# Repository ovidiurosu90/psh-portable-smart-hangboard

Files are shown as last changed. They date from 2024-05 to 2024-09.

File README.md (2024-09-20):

# [PSH Portable Smart Hangboard](https://github.com/ovidiurosu90/psh-portable-smart-hangboard)

## Abstract
### Problem
Help people get better at climbing by improving their finger strength

### Solution
Provide a portable smart hangboard to use for finger strength training

### How
- the whole project is open-source, and can be replicated by interested parties (note it requires a variety of skills like setting up a web server, 3d printing, soldering & crimping)
- the hangboard measures the pressure applied to the hanghold by using a couple of load cells
- the training plans are set in Google Sheets

## Important Links

| Name | README |
| --- | --- |
| BOM Bill Of Materials | [BOM.md](BOM.md) |
| How To Build | [HOWTOBUILD.md](HOWTOBUILD.md) |

## Images

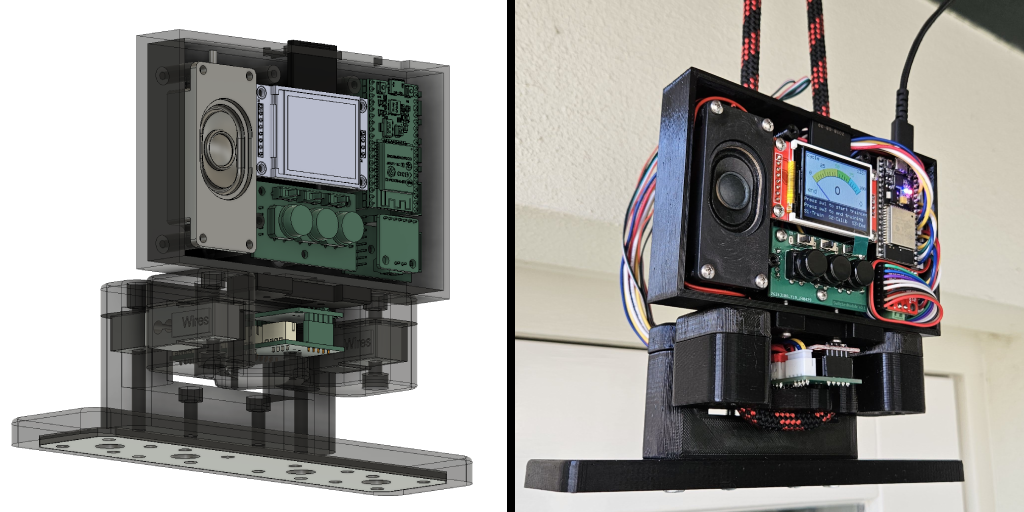
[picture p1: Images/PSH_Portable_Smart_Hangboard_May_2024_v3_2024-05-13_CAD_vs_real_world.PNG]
CAD vs Real World


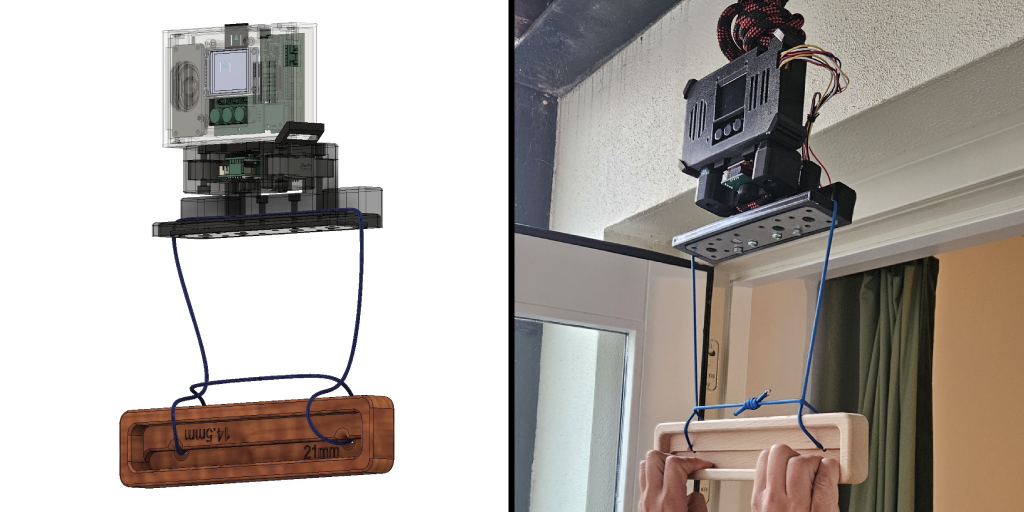
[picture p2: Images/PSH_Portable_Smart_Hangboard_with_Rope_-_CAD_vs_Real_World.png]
Wood non-slippery holds - CAD vs Real World


## Functionality of switches
- There are 3 big black momentary switches (labeled SW1, SW2 and SW3)
- There are 3 small toggle switches (labeled SW4, SW5 and SW6)
- The functionality of the switches is described below

### SW1
If SW4 is toggled ON: start training

Else: decrease volume

### SW2
If SW4 is toggled ON: start calibrating

Else: store volume into NVS (only if SW5 is toggled ON)

### SW3
If SW4 is toggled ON: end training

Else: increase volume

### SW4
If toggled ON: show train menu

Else: show volume menu

### SW5
If toggled ON: allow NVS to be updated (for calibration and for volume)

Else: don't allow NVS to be updated

### SW6
Not used at the moment

## Usage
- Power the microcontroller via its micro-USB port (+5V)
- Wait for the microcontroller to finish setting things up (it's ready when it says 'idle' on the lower left side of analog meter)
- Configure the training parameters in the spreadsheet via Goole Sheets
- The training program starts with a rest cycle, followed by an activity cycle, then repeat
- Example

| totalCycles | activityTotalSeconds | restTotalSeconds | scaleLowerLimitGrams | scaleUpperLimitGrams |
| --- | --- | --- | --- | --- |
| 6 | 10 | 20 | 55000 | 90000 |

- For the example above, we'll have 6 cycles as follows:
    - cycle 1: rest for 20 seconds
    - cycle 2: activity for 10 seconds
    - cycle 3: rest for 20 seconds
    - cycle 4: activity for 10 seconds
    - cycle 5: rest for 20 seconds
    - cycle 6: activity for 10 seconds

- Start the training by pressing SW1 (note SW4 should be toggled ON)
- The score is updated only in the activity cycles (cycle 2, 4 and 6 in the example above)
- The score is calculated as follows:
    - each second there are 2 scale measurements
    - let's say we have 3 activity cycles of 10 seconds
    - which means 3x 10x 2 measurements
    - we just sum up the 60 measurements (in kg)
- For the exapmle above, the score can be the following:
    - score: 2017 (which is a sum of all the scale measurements)
    - history: 73,70,70,68,71,70,70,70,69,70,62,65,67,68,66,66,66,67,64,64,68,66,67,67,67,65,66,67,65,63
- In the future, the scoring method may be different, as at the moment, we don't penalize out-of-bounds measurements, and we don't reward in-bounds measurements

## Wiring

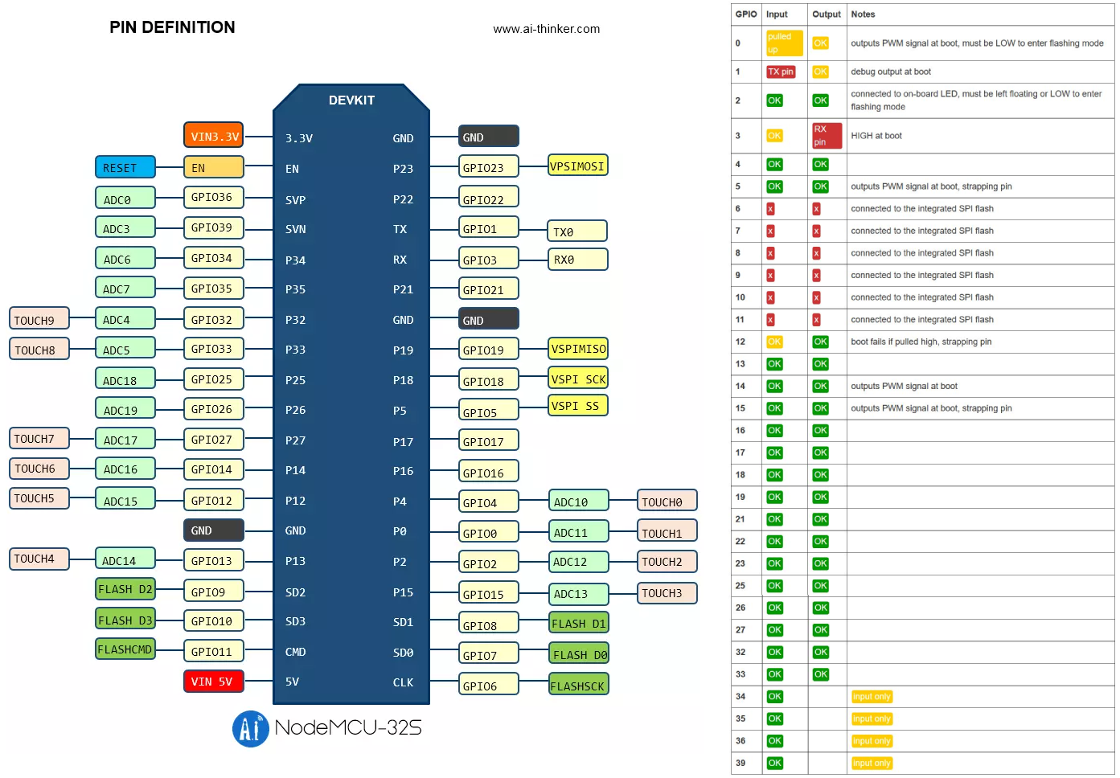
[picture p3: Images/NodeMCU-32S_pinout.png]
NodeMCU 32S Pinout


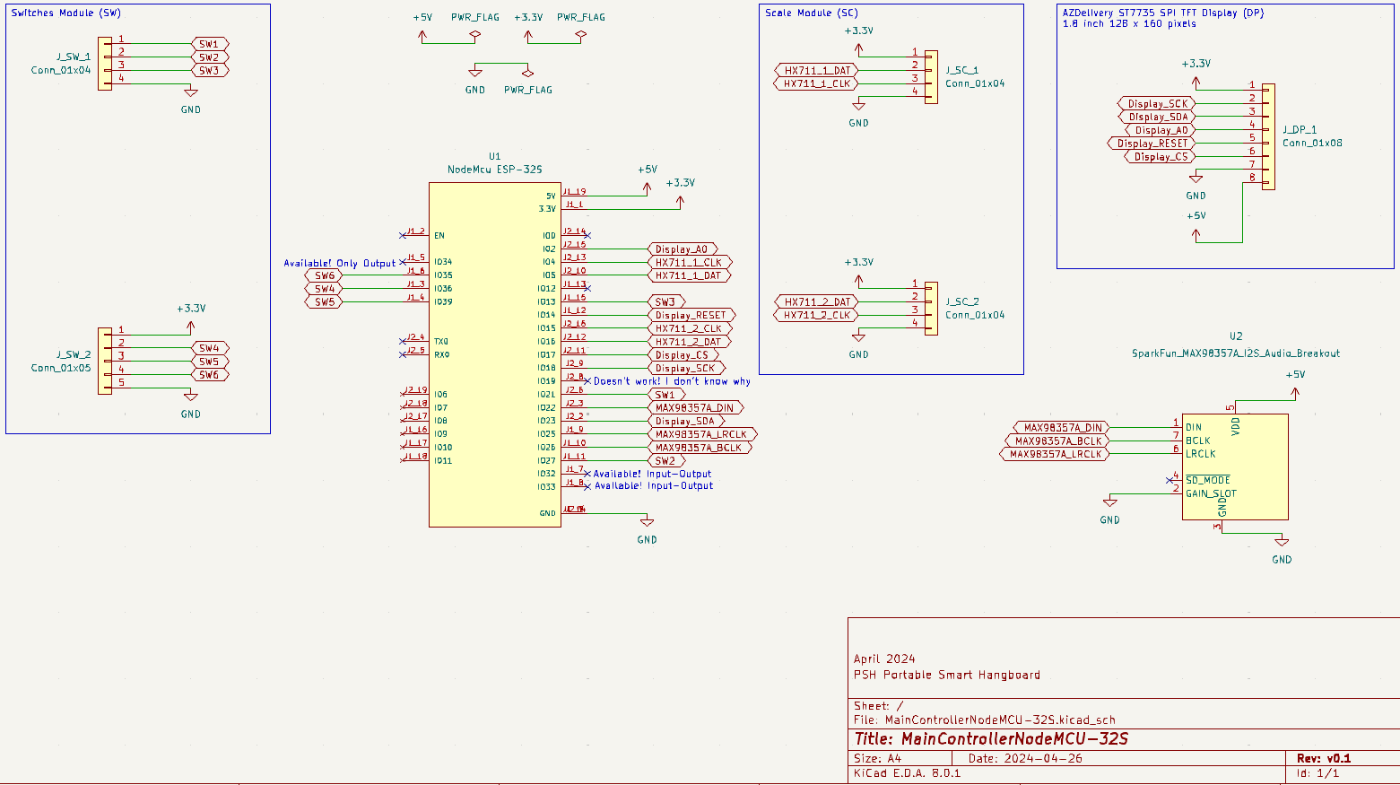
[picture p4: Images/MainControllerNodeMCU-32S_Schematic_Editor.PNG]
MainControllerNodeMCU-32S Schematic Editor


| [NodeMcu ESP-32S Lua ESP-WROOM-32](https://opencircuit.shop/product/nodemcu-esp-32s-lua-esp-wroom-32-wifi) | [SparkFun HX711 Load Cell Amplifier](https://eu.robotshop.com/products/hx711-load-cell-amplifier?variant=42600661942440) => NOTE we need to solder male pins |
| --- | --- |
| 5, 4 | DAT1, CLK1 |
| 16, 15 | DAT2, CLK2 |
| +3.3V | VDD, VCC |
| GND | GND |

| [NodeMcu ESP-32S Lua ESP-WROOM-32](https://opencircuit.shop/product/nodemcu-esp-32s-lua-esp-wroom-32-wifi) | [AZDelivery ST7735 SPI TFT Display 1.8 inch 128 x 160 pixels](https://www.amazon.nl/dp/B078J5TS2G/ref=pe_28126711_487805961_TE_item?th=1) =>  [guide](https://www.az-delivery.de/en/blogs/azdelivery-blog-fur-arduino-und-raspberry-pi/1-8-toll-tft-am-esp-32-dev-kit-c-betreiben) |
| --- | --- |
| +5V | VCC |
| GND | GND |
| G17 | CS |
| G14 | Reset / RST |
| G2 | A0 / DC |
| G23 | Sda / MOSI |
| G18 | Sck / SCLK |
| 3.3V | LED |

| [NodeMcu ESP-32S Lua ESP-WROOM-32](https://opencircuit.shop/product/nodemcu-esp-32s-lua-esp-wroom-32-wifi) | [AZDelivery ST7735 SPI TFT Display 1.8 inch 128 x 160 pixels](https://www.amazon.nl/dp/B078J5TS2G/ref=pe_28126711_487805961_TE_item?th=1) => [guide](https://randomnerdtutorials.com/guide-to-1-8-tft-display-with-arduino/) |
| --- | --- |
| G33 | CS |
| G23 | MOSI (shared with display) |
| G19 | MISO |
| G18 | SCK / SCLK (shared with display |

NOTE At the moment the custom PCB for the MainControllerNodeMCU-32S module needs a small improvement. Currently it’s missing a 4-pin connection for interfacing with the SD card on the TFT display. You can either modify the project and add the connector on the PCB (before placing the order), or make the 4 connections manually (solder the 4 wires directly on the PCB, picture found below). Follow the issue on GitHub for updates: [\[PCB\] Update Custom PCB for MainControllerNodeMCU-32S #8](https://github.com/ovidiurosu90/psh-portable-smart-hangboard/issues/8).

| [NodeMcu ESP-32S Lua ESP-WROOM-32](https://opencircuit.shop/product/nodemcu-esp-32s-lua-esp-wroom-32-wifi) | [SparkFun MAX98357A I2S Audio Breakout](https://opencircuit.shop/product/sparkfun-i2s-audio-breakout-max98357a) => [guide](https://learn.sparkfun.com/tutorials/i2s-audio-breakout-hookup-guide/all) |
| --- | --- |
| +5V (if we use +3.3V the volume fluctuates) | VDD |
| GND | GND |
| \- | SD |
| GND | GAIN (+12dB, without this it will be +9dB) |
| G22 | DIN / DOUT |
| G26 | BCLK |
| G25 | LRCLK |

| [NodeMcu ESP-32S Lua ESP-WROOM-32](https://opencircuit.shop/product/nodemcu-esp-32s-lua-esp-wroom-32-wifi) | SwitchesModule (my custom PCB) |
| --- | --- |
| G21 | SW1 |
| G27 | SW2 |
| G13 | SW3 |
| GND | GND |
| +3.3V | ~ pull-up resistors |
| G36 | SW4 with 10k resistor to +3.3V |
| G39 | SW5 with 10k resistor to +3.3V |
| G35 | SW6 with 10k resistor to +3.3V |
| GND | GND |

| [NodeMcu ESP-32S Lua ESP-WROOM-32](https://opencircuit.shop/product/nodemcu-esp-32s-lua-esp-wroom-32-wifi) | ? |
| --- | --- |
| G32 (input-output pin) | Available |
| G34 (only output pin) | Available |

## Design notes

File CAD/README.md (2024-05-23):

# CAD
I am using Autodesk Fusion 360 as the main CAD software.
In this folder you can find the .f3z file, which contains all the .f3d Fusion 360 3D design files. I chose to upload the f3z file instead of a bundle of STEP files as it holds the complete design and it's way easier to update.

NOTE Install Autodesk Fusion 360, then import everything by following the steps:

1. create a new project by clicking ‘New Project’ in the left toolbar
1. open the new project by double clicking its name
1. upload the .f3d archive from GitHub ([CAD](CAD)) by clicking ‘Upload’ in the left toolbar
1. wait a few minutes, this is uploading multiple designs to your Fusion 360 project
1. open the main assembly (PSH Portable Smart Hangboard May 2024) by double clicking its name. It should look something like this

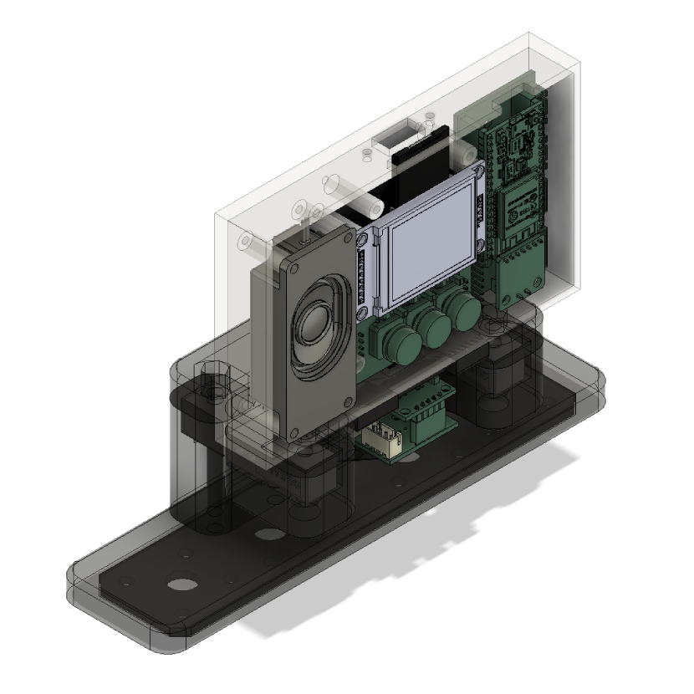
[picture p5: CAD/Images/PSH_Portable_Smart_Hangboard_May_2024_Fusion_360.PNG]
PSH Portable Smart Hangboard May 2024 in Fusion 360


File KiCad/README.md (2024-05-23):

# KiCad
I am using KiCad 8.0 as the main electronics design software. The project at the moment has 3 custom PCBs that were designed with this tool.
You have to send the gerber files to a PCB manufacturer, then solder the connectors / components before assembling.

## Images

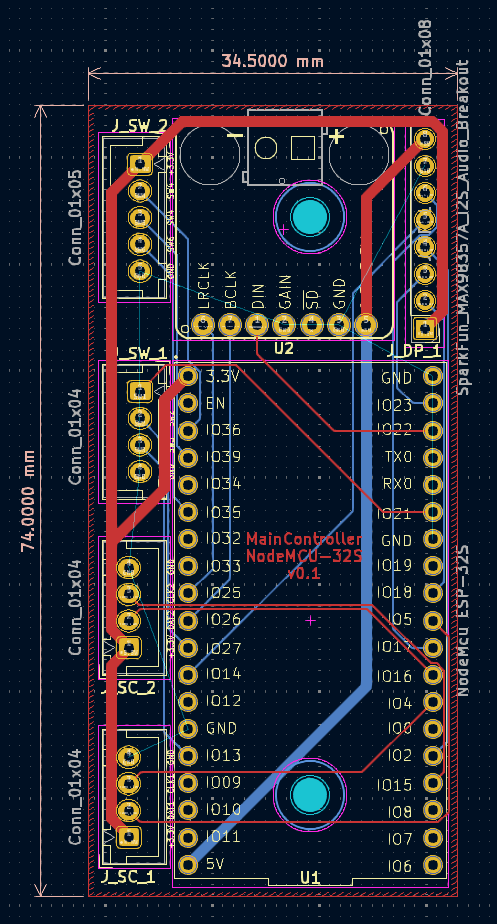
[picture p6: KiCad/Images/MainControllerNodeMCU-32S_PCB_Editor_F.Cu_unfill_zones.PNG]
MainControllerNodeMCU-32S PCB Editor F.Cu unfill zones


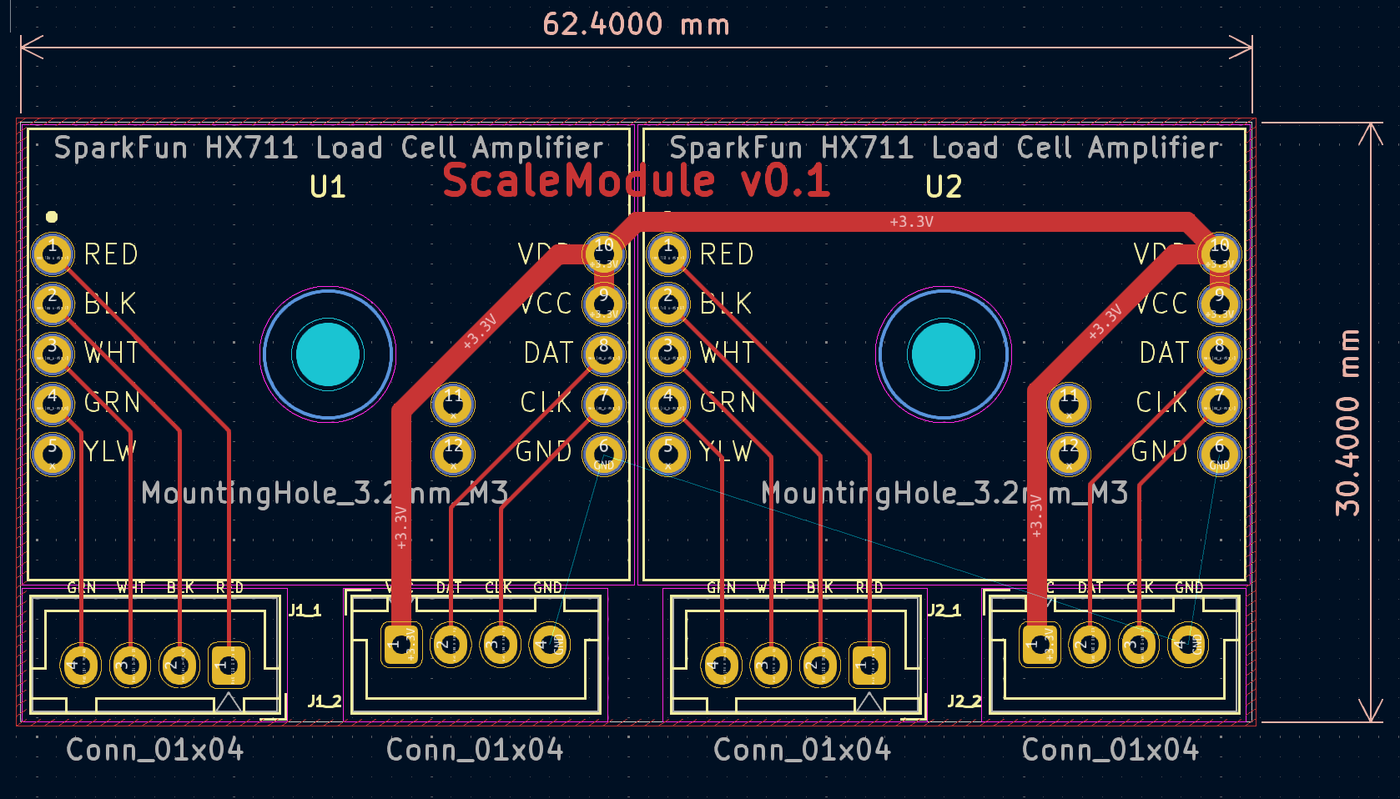
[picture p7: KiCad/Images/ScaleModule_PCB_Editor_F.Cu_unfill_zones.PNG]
ScaleModule PCB Editor F.Cu unfill zones


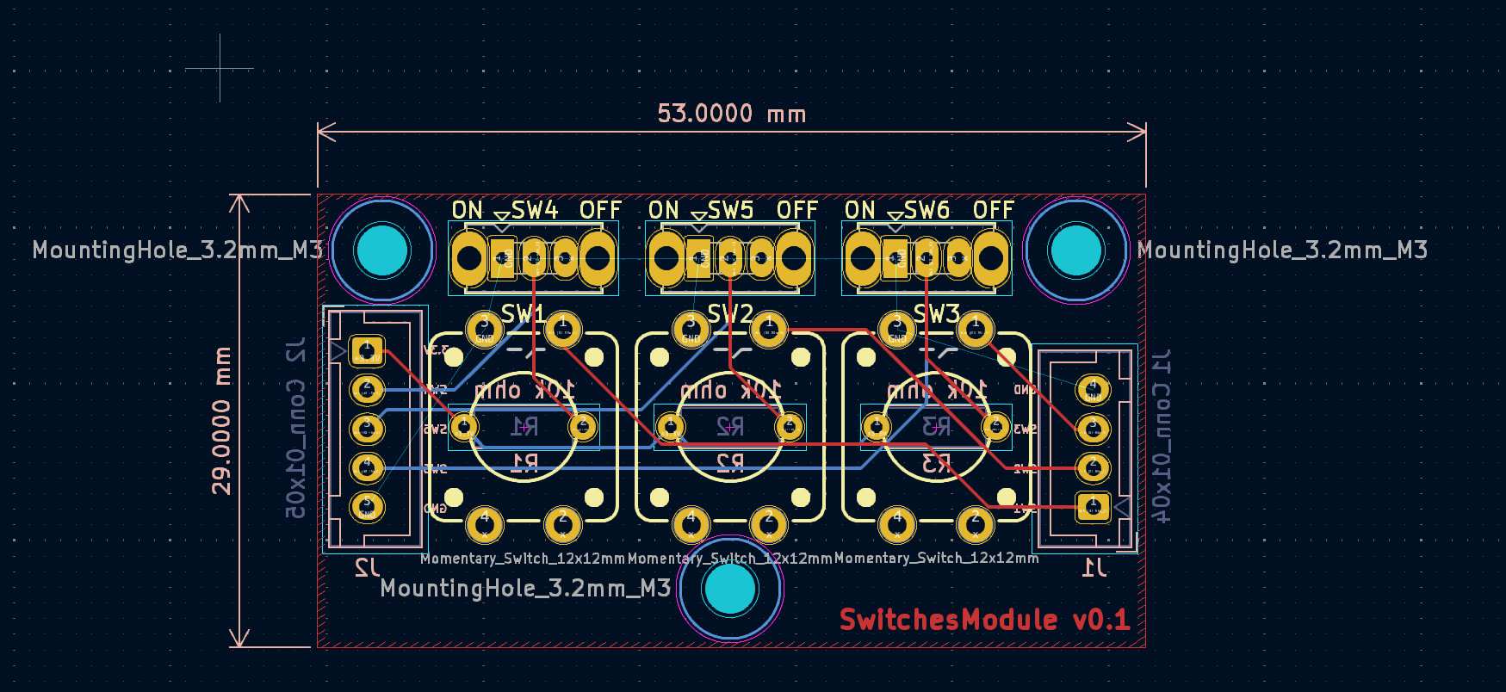
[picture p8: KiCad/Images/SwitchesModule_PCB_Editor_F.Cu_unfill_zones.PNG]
SwitchesModule PCB Editor F.Cu unfill zones


## Configuration
### PCB Layers
- F.Cu => tracks & maybe name + version
- B.Cu => tracks & maybe name + version
- F.Adhesive => vias + pads
- B.Adhesive => vias + pads
- F.Paste => vias + pads
- B.Paste => vias + pads
- F.Silkscreen => labels front
- B.Silkscreen => labels back + pcb dimensions (NOTE in 3D Viewer, you have to make visible Off-board Silkscreen)
- F.Mask => pads
- B.Mask => pads
- User.Comments => mounting holes exterior
- Edge.Cuts => pcb edges
- F.Courtyard => edges components on the pcb front
- B.Courtyard => edges components on the pcb back
- F.Fab => references footprints front
- B.Fab => references footprints back

### Design Rules -> Constraints
- Minimum track width 0.2 mm
- Minimum via diameter => 0.7 mm
- Minimum through hole => 0.4 mm
- Hole to hole clearance => 0.25mm
- Minimum uVia diameter => 0.7 mm
- Minimum uVia hole => 0.4mm
- Minimum text height => 0.5mm

### Design Rules -> Net Classes
- Default
    - Clearance 0.2 mm
    - Track Width 0.2 mm
    - Via Size 0.6 mm
    - Via Hole 0.3 mm
    - uVia Size 0.3 mm
    - uVia Hole 0.1 mm
    - DP Width 0.2
    - DP Gap 0.25 mm
- Custom
    - Clearance 0.3 mm
    - Track Width 0.3 mm
    - Via Size 0.8 mm
    - Via Hole 0.4 mm
    - uVia Size 0.6 mm
    - uVia Hole 0.2 mm
    - DP Width 0.2
    - DP Gap 0.25 mm
- Power
    - Clearance 0.8 mm
    - Track Width 0.8 mm
    - Via Size 1.2 mm
    - Via Hole 0.6 mm
    - uVia Size 0.6 mm
    - uVia Hole 0.2 mm
    - DP Width 0.2
    - DP Gap 0.25 mm

### Design Rules -> Pre-defined Sizes
- Tracks 1 mm width
- Vias 1.2 mm diameter, 1 mm hole
*Tracks: 1 mm for power, netclass width for everything else*

## Validation
A. Schematic Editor
1. Annotate Schematic => make screenshots
2. Electrical Rules Checker
3. Assign Footprints => make screenshots

B. PCB Editor
0. File -> Board Setup -> Import Settings from Another Board...
1. Check F.Cu with unfill zones => make screenshots
2. Check B.Cu with unfill zones => make screenshots
3. Check F.Cu with fill zones => make screenshots
4. Check B.Cu with fill zones => make screenshots
5. Check 3D Viewer front (toggle Through-hole Models on & off) => make screenshots
6. Check 3D Viewer back (toggle Through-hole Models on & off) => make screenshots

7. Check the connections
8. Check order & orientation of the pins for the connectors (e.g. JST-XH)
9. Check pcb size
10. Check version on both F.Cu / B.Cu & page print

11. Update PCB From Schematic (uncheck Delete footprints with no symbols)
12. Design Rules Checker

## Generate Gerber & Drill files
Check [wiki from JLCPCB](https://jlcpcb.com/help/article/362-how-to-generate-gerber-and-drill-files-in-kicad-7)

1. In PCB Editor => File => Fabrication Outputs => Gerbers
2. Select Output directory: Outputs
3. Include Layers
    * F.Cu
    * B.Cu
    * F.Paste
    * B.Paste
    * F.Silkscreen
    * B.Silkscreen
    * F.Mask
    * B.Mask
    * Edge.Cuts
4. Check Plot reference designators
5. Check Check zone files before plotting
6. Check Use Protel filename extensions
7. Check Subtract soldermask from silkscreen

8. Click Plot

9. Click Generate Drill Files
10. Check Use alternate drill mode
11. Check Absolute for Drill Origin
12. Check Milimeters for Drill Units
13. Check Decimal format for Zeros Format

14. Click Generate Drill File
15. Click Generate Map File

## Verify generated Gerber files
* Open Gerber Viewer in KiCad
* File -> Open Excellon Drill File (do it once for each drill file you have)
* File -> Open Gerber Plot File => Edge_Cuts
* File -> Open Gerber Plot File => F_Silkscreen
* File -> Open Gerber Plot File => F_Mask
* File -> Open Gerber Plot File => F_Cu
* File -> Open Gerber Plot File => B_Silkscreen
* File -> Open Gerber Plot File => B_Mask
* File -> Open Gerber Plot File => B_Cu

* Create a zip file from all the files in the Outputs directory & add the version & date to the name (e.g. *MainControllerNodeMCU-32S-v0.1-20240428.zip*)

## Add the zip to your PCB manufacturer (e.g.)
* Go to https://cart.jlcpcb.com/quote
* Check dimensions (auto-generated)
* Check version (on the PCB)
* Select black or white (if it's not too expensive or slow)
* Check mounting holes

* IMPORTANT Check if you want to create or update another board, to save on transport

# Task List
## MainControllerNodeMCU-32S v0.1-20240428
- NOTE At the moment the custom PCB for the MainControllerNodeMCU-32S module needs a small improvement. Currently it’s missing a 4-pin connection for interfacing with the SD card on the TFT display. You can either modify the project and add the connector on the PCB (before placing the order), or make the 4 connections manually (solder the 4 wires directly on the PCB, picture found below). Follow the issue on GitHub for updates: [\[PCB\] Update Custom PCB for MainControllerNodeMCU-32S #8](https://github.com/ovidiurosu90/psh-portable-smart-hangboard/issues/8)

## ScaleModule v0.1-20240428
- All done

## SwitchesModule v0.1-20240428
- All done

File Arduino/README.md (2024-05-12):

# Arduino
Programming the microcontroller was done using [PlatformIO](https://platformio.org/) - Arduino framework.

Before uploading the firmware to the microcrontroller, we have to set a few configuration parameters.
```bash
cd MainControllerNodeMCU-32S/config/
cp secret.ini.dist secret.ini
vim secret.ini and fill in the proper values
```

I use a custom made script that bundles a few of the PlatformIO together, though in short, these are the steps to be run to program the microcontroller:
```bash
platformio pkg update
platformio run
platformio run --target upload
platformio device monitor --port /dev/O_ttyUSB0 --baud 115200 | ts [%Y-%m-%d %H:%M:%S] | tee -a MainControllerNodeMCU-32S.log
```

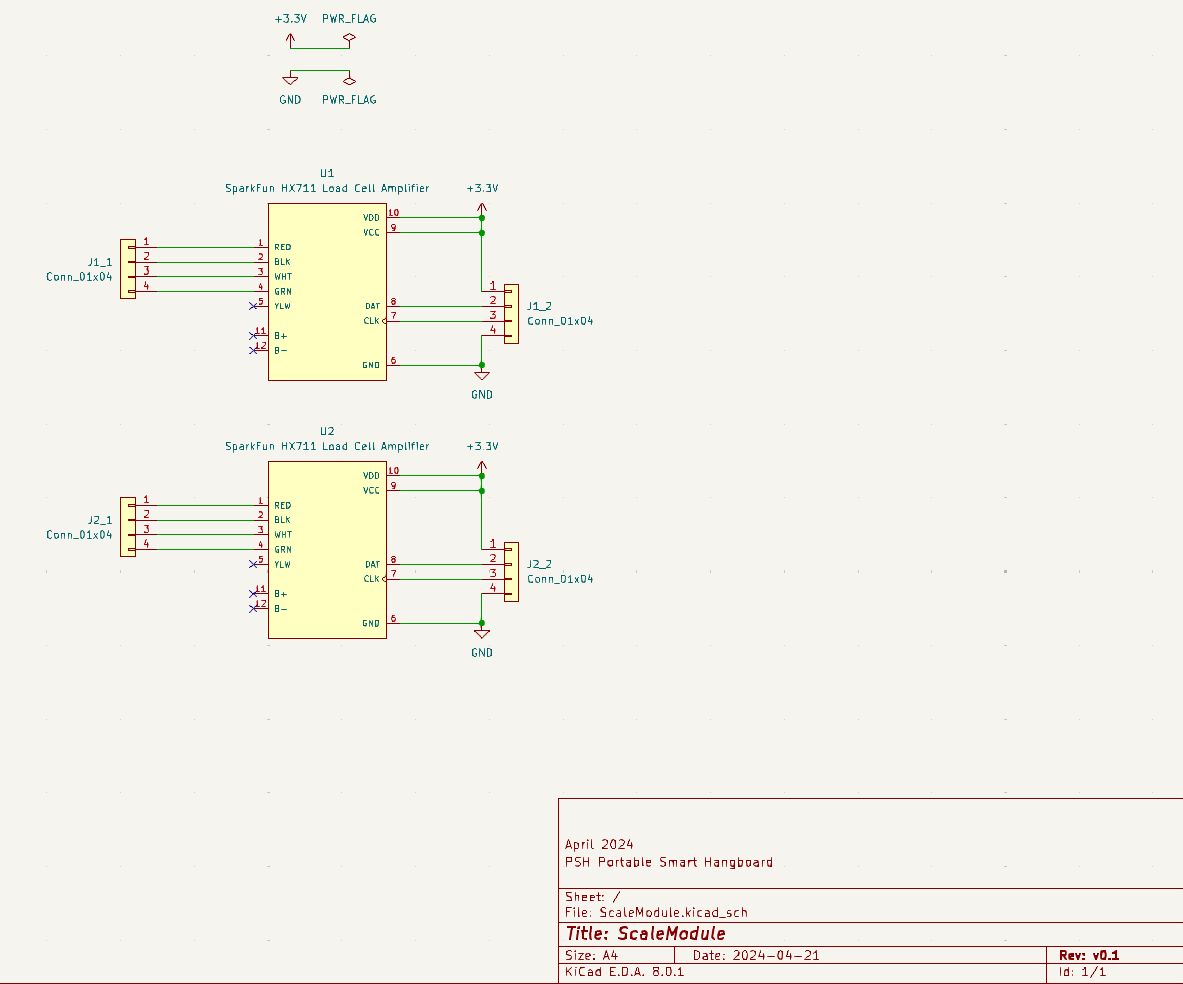
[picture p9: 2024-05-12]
KiCad/ScaleModule/Screenshots/01_Schematic Editor.PNG

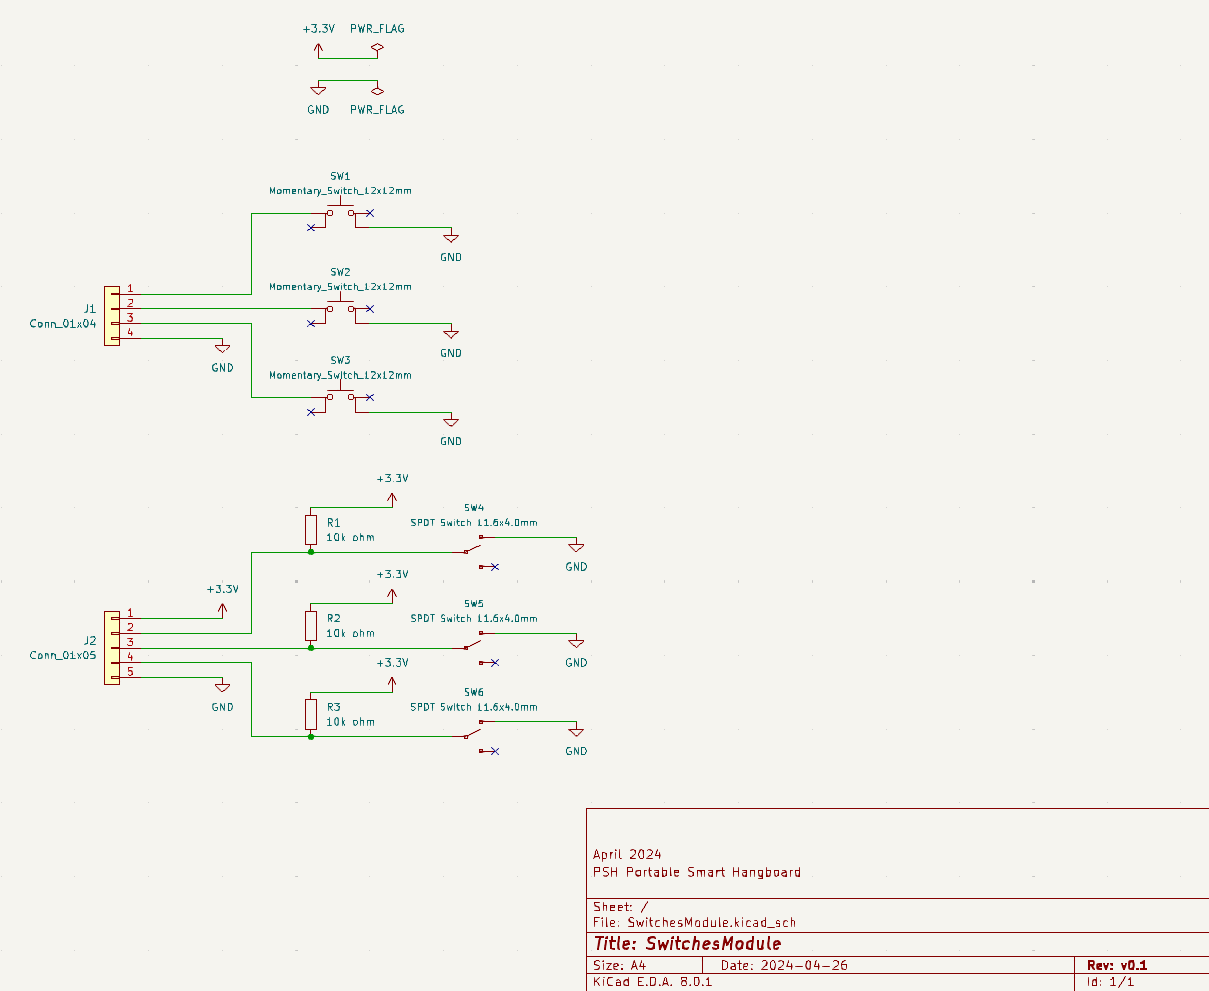
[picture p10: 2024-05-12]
KiCad/SwitchesModule/Screenshots/01_Schematic Editor.PNG

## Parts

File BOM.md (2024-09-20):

# BOM Bill Of Materials
NOTE These are the components and suppliers I used, though you're free to use others. I am not getting any commission for adding these links here.

NOTE The prices are excluding transportation.

## Electronic Components
- [ ] 2x [50 Kg Micro Load Cell](https://eu.robotshop.com/products/micro-load-cell-50-kg?variant=42601477177512) (9.33€ / unit)
- [ ] 2x [SparkFun HX711 Load Cell Amplifier](https://eu.robotshop.com/products/hx711-load-cell-amplifier?variant=42600661942440) (11.19€ / unit)
- [ ] 1x [SparkFun MAX98357A I2S Audio Breakout](https://opencircuit.shop/product/sparkfun-i2s-audio-breakout-max98357a) (6.45€)
- [ ] 1x [Adafruit Speaker 3W 4 Ohm Mono Enclosed](https://opencircuit.shop/product/mono-enclosed-speaker-3w-4-ohm) (7.95€)
- [ ] 1x [AZDelivery ST7735 SPI TFT Display 1.8 inch 128 x 160 pixels](https://www.amazon.nl/dp/B078J5TS2G/) (7.50€)
- [ ] 1x 8GB MicroSD Card (9€)
- [ ] 1x [NodeMcu ESP-32S Lua ESP-WROOM-32](https://opencircuit.shop/product/nodemcu-esp-32s-lua-esp-wroom-32-wifi) (15€)
- [ ] 3x [Momentary switch 12x12mm black](https://opencircuit.shop/Product/Tactiele-button-12x12x7.3mm-black-5-pcs) (2.25€ / set)
- [ ] 3x [SPDT Switch 11.6x4.0mm](https://opencircuit.shop/product/schuifschakelaar-2x-wissel) (1.45€ / set)
- [ ] 3x 10k resistor (1€ / set)

## Wires & connectors
- [ ] 8x [Jumper cables with dupont connector female to female 30cm](https://www.123-3d.nl/123-3D-Jumper-kabel-dupont-vrouwelijk-naar-vrouwelijk-30-cm-40-stuks-i3161-t13138.html) (4.73€ / set)
- [ ] 1x [Adafruit 22AWG Stranded-Core Wire Spool Set](https://opencircuit.shop/product/hook-up-wire-spool-set-22awg-stranded-core-6-x) (31.95€ / set)
    - 2x 4-wire 38cm for ScaleModule
    - 3x 4-wire 22cm for SmartBox

- [ ] 100x [JST-XH female crimp terminal](https://opencircuit.shop/product/jst-xh-female-crimp-terminal-22awg-100-stuks) (3.55€ / set)
- [ ] 10x JST-XH 4-pin male
- [ ] 10x JST-XH 4-pin female
- [ ] 2x JST-XH 5-pin male
- [ ] 2x JST-XH 5-pin female
- [ ] 1x JST-XH 8-pin male
- [ ] 1x JST-XH 8-pin female
- [ ] 1x Screw Terminal 3.5mm Pitch - 2-Pin

## Screws & bolts
- [ ] 25x [2.9x9.5mm self-tapping - plate pan head screws](https://www.rvspaleis.nl/plaatschroeven/din-7981-h/din-7981h-\[-]-a2-\[-]-2,9/7981-2-2.9x9.5h_100) (3.87€ / set)
- [ ] 2x 2.9x13mm self-tapping - plate pan head screws
- [ ] 2x M5x60mm or 65mm - internal hex head bolts (threaded all the way)
- [ ] 4x M5x30mm - internal hex head (threaded all the way)
- [ ] 10x M5 nuts

## Tools & consumables
- [ ] 1x [Velleman soldering tin - 0.6mm rosin core - 100g](https://opencircuit.shop/product/velleman-soldering-tin-0.6mm-rasin-core-100g) (11.75€)
- [ ] 1x [REAL filament PETG 1.75mm black 3 kg](https://www.123-3d.nl/REAL-filament-zwart-1-75-mm-PETG-3-kg-i10317-t7396.html) (82.5€ | you can order less)
- [ ] 1x Wire Crimping Tool
- [ ] 1x 3D Printer
- [ ] 1x Soldering Station

## Others
- [ ] 1x [Alberts metal flat plate 180x40x3mm](https://www.praxis.nl/gereedschap-installatiemateriaal/ijzerwaren/ankerwerk/alberts-verbindingsplaat-ruwstaal-verzinkt-180x40x3mm/6282142) (1.35€)
- [ ] 1x 2m 9mm climbing rope
- [ ] 2x climbing carabiner for easier mounting (optional)
- [ ] 1x Wood non-slippery holds => [Portable hangboard "Stella"](https://www.etsy.com/listing/1724835154/portable-hangboard-stella-for-warming-up)

## For Programming (optional, you can use your laptop directly)
- [ ] 1x [Raspberry Pi 4 Model B / 8GB](https://www.sossolutions.nl/raspberry-pi-4-model-b-8gb) (90€)
- [ ] 1x [Original Raspberry Pi USB-C 3A power supply Black](https://www.sossolutions.nl/originele-raspberry-pi-foundation-usbc-3a-voeding-zwart) (11€)
- [ ] 1x [SanDisk Extreme Memory Card, Red/Gold 64GB](https://www.amazon.nl/dp/B07G3GMRYF) (18€)
- [ ] 1x [Micro HDMI to HDMI Adapter Cable](https://www.sossolutions.nl/micro-hdmi-naar-hdmi-adapterkabel) (6€)

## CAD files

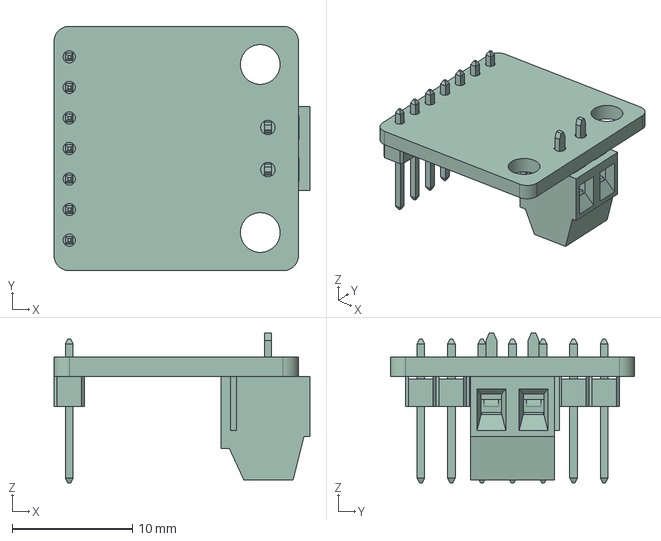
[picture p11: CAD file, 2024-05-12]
KiCad/MainControllerNodeMCU-32S/3D Models/SparkFun MAX98357A I2S Audio Breakout v3.step
21.3 x 20.3 x 12.4 mm

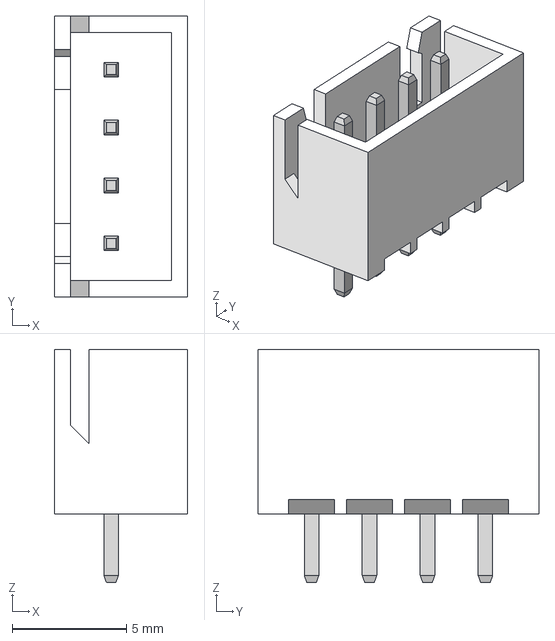
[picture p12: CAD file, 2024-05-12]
KiCad/ScaleModule/3D Models/4-Pin JST-XH - Male Vertical - 2.54mm v3.step
5.84 x 12.3 x 10.2 mm

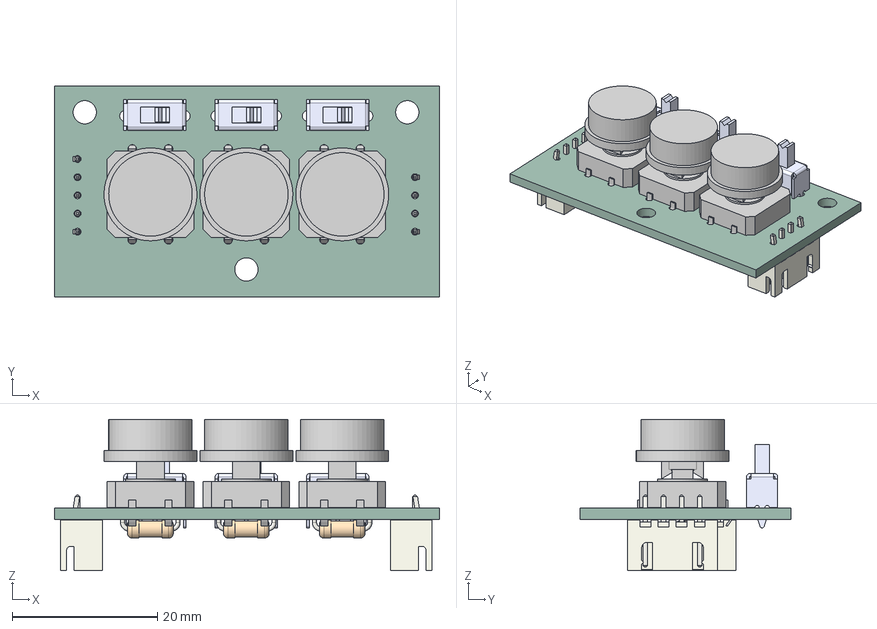
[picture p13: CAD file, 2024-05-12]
KiCad/SwitchesModule/3D Models/SwitchesModule v0.1.step
53.0 x 29.0 x 20.9 mm
Momentary Switch 12x12mm v2 x 3
SPDT Switch 11.6x4.0mm v2 x 3
R_Axial_DIN0207_L63mm_D25mm_P762mm_Horizontal x 3
JST_B4B_XH_A
JST_B5B_XH_A
SwitchesModule_PCB

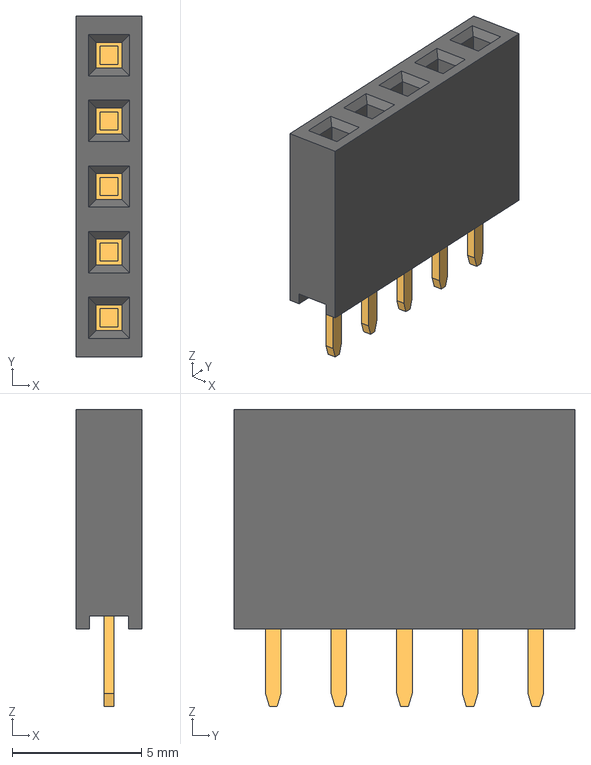
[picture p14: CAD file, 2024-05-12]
KiCad/ScaleModule/3D Models/5-Pin Header - Female Tall - 2.54mm v2.step
2.54 x 13.2 x 11.5 mm

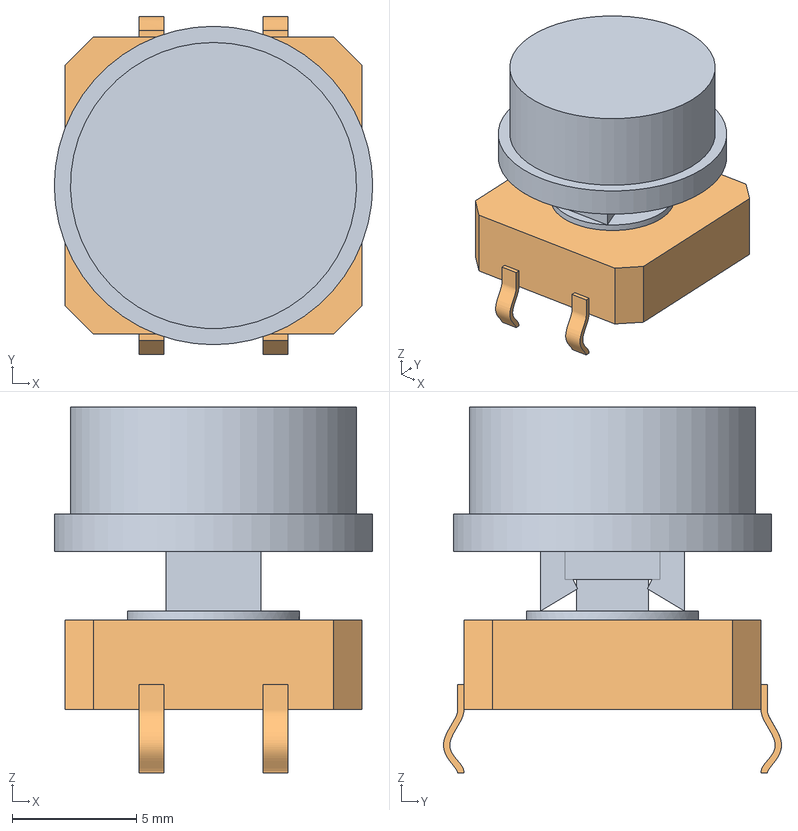
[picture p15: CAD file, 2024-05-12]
KiCad/SwitchesModule/3D Models/Momentary Switch 12x12mm v2.step
12.8 x 13.6 x 14.7 mm

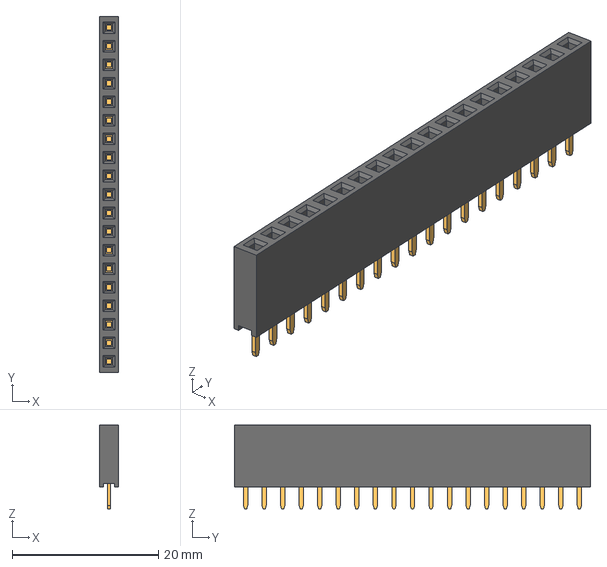
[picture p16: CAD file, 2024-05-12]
KiCad/MainControllerNodeMCU-32S/3D Models/19-Pin Header - Female Tall - 2.54mm v2.step
2.54 x 48.8 x 11.5 mm

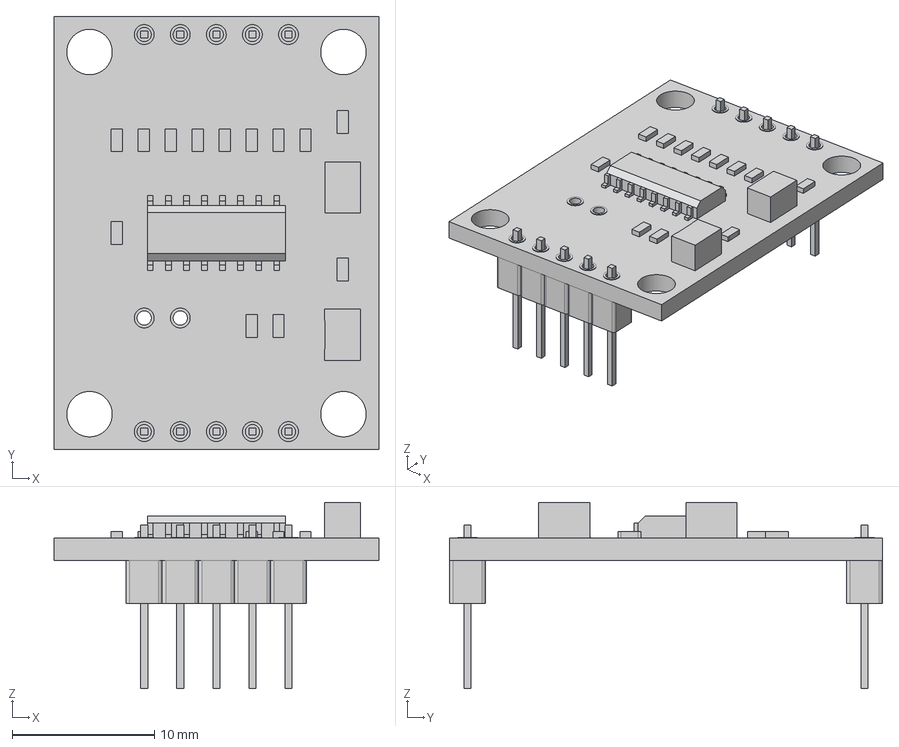
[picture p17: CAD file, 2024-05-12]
KiCad/ScaleModule/3D Models/SparkFun HX711 Load Cell Amplifier v4.step
22.9 x 30.5 x 13.1 mm

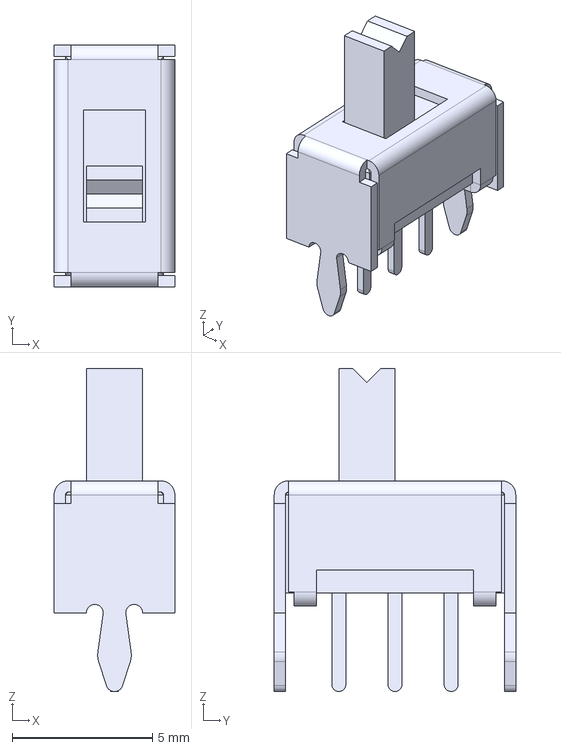
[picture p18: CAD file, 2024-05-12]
KiCad/SwitchesModule/3D Models/SPDT Switch 11.6x4.0mm v2.step
4.30 x 8.60 x 11.5 mm

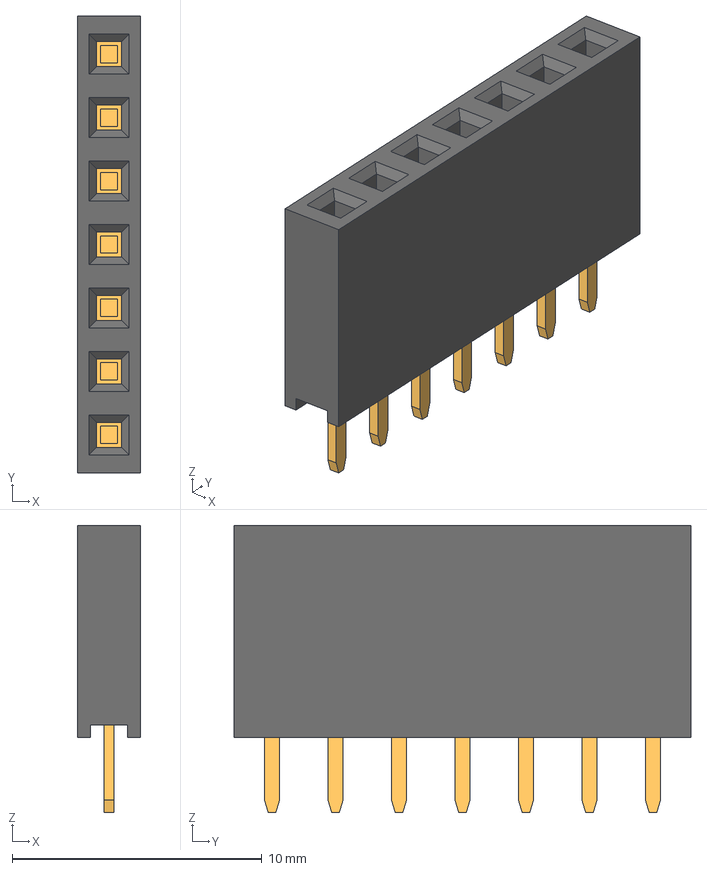
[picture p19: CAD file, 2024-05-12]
KiCad/MainControllerNodeMCU-32S/3D Models/7-Pin Header - Female Tall - 2.54mm v2.step
2.54 x 18.3 x 11.5 mm

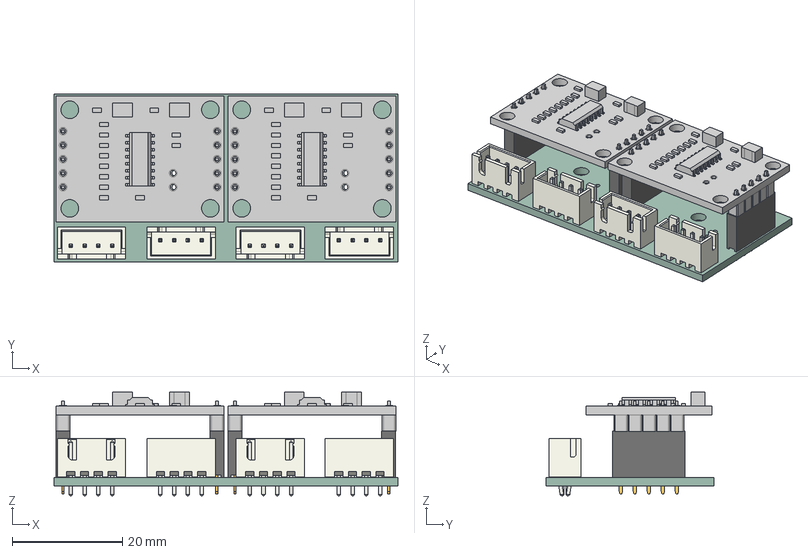
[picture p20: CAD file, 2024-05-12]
KiCad/ScaleModule/3D Models/ScaleModule v0.1.step
62.4 x 30.4 x 18.8 mm
JST_B4B_XH_A x 4
5-Pin Header - Female Tall - 2.54mm v2 x 4
SparkFun Load Cell Amplifier HX711 v4 x 2
ScaleModule_PCB

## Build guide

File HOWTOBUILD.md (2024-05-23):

# How to build your own PSH Portable Smart Hangboard

## Order the 3 custom PCBs
NOTE At the moment the custom PCB for the MainControllerNodeMCU-32S module needs a small improvement. Currently it's missing a 4-pin connection for interfacing with the SD card on the TFT display. You can either modify the project and add the connector on the PCB (before placing the order), or make the 4 connections manually (solder the 4 wires directly on the PCB, picture found below). Follow the issue on GitHub for updates: [\[PCB\] Update Custom PCB for MainControllerNodeMCU-32S #8](https://github.com/ovidiurosu90/psh-portable-smart-hangboard/issues/8)

NOTE Install KiCad 8.0, and for each of the 3 modules (MainControllerNodeMCU-32S, ScaleModule and SwitchesModule) follow the steps:

1. Open folder as a project (File > Open Project...)
1. Open PCB Editor
1. Generate Gerber & Drill files by following the notes from [KiCad/README.md](KiCad/README.md)
1. Archive all the generated files into a .zip file
1. Upload the .zip file to your PCB manufacturer
1. Place the order for your PCB manufacturer

NOTE When they arrive, they should look like this:

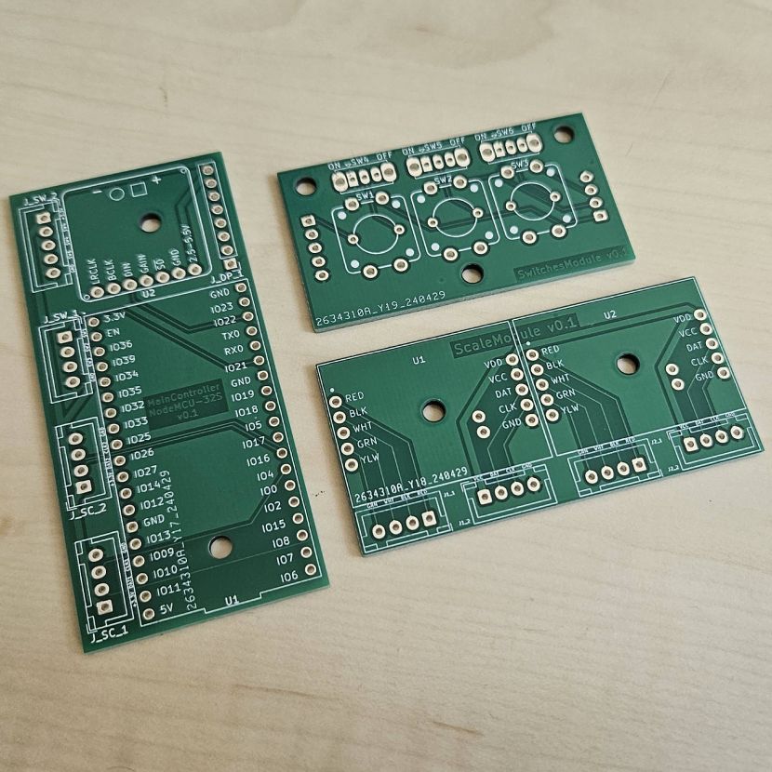
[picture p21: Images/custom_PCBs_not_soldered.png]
Custom PCBs - not soldered


## Procure the components
Check the Bill Of Materials ([BOM.md](BOM.md)), and order the components listed there.

## Crimp the relevant JST-XH connectors

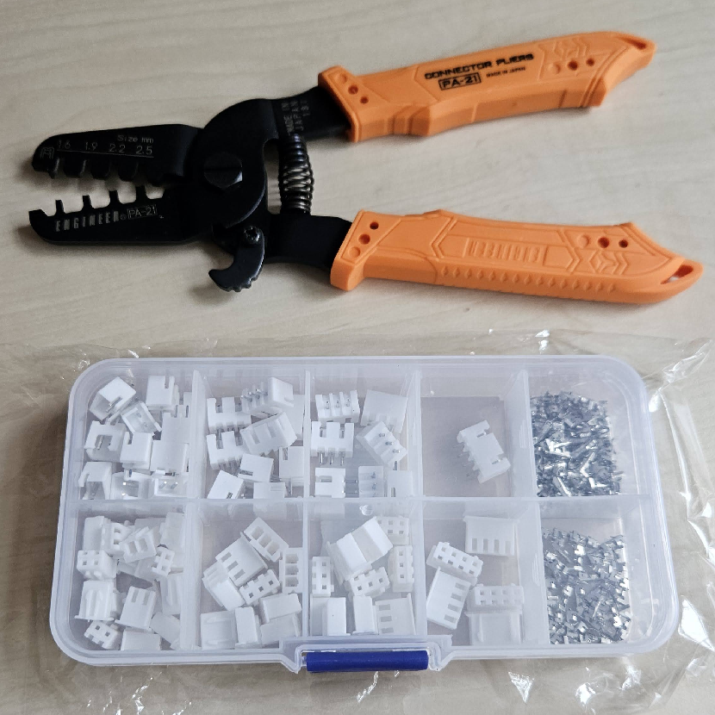
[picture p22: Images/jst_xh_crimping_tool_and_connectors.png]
JST-XH crimping tool and connectors


1. Crimp one JST-XH 4-pin female headers to each of the two load cells. Mine ([50 Kg Micro Load Cell](https://eu.robotshop.com/products/micro-load-cell-50-kg?variant=42601477177512)) came with small dupont male 4-pin headers crimped to super thin wires, which I replaced with the JST-XH headers.

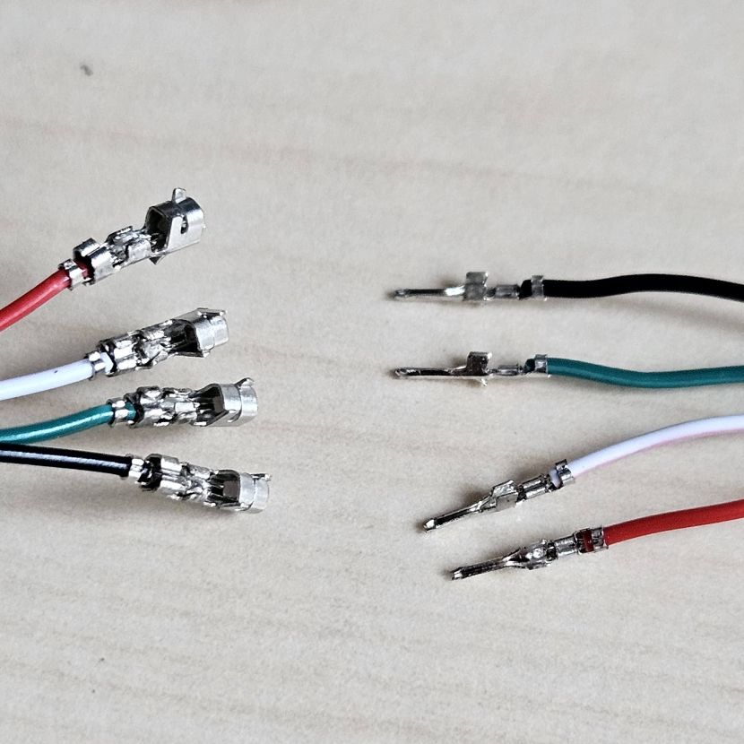
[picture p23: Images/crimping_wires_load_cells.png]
Crimping wires load cells


NOTE [Verify the wires](https://circuitjournal.com/four-wire-load-cell-with-HX711) of the load cells with a multimeter, and measure the resistance between all possible pairs. Identify the 2 pairs with the highest resistance, in my case that's 1 k ohm (red-black & white-green), while all the other combinations have a resistance of 750 ohm. This will help you identify the correct configuration in order to connect them to the [SparkFun HX711 Load Cell Amplifier](https://eu.robotshop.com/products/hx711-load-cell-amplifier?variant=42600661942440).

2. Build the wires for the connections between different components (we use 4-pin JST-XH headers)
    - 2x 4-wire 38cm for ScaleModule
    - 3x 4-wire 22cm for SmartBox

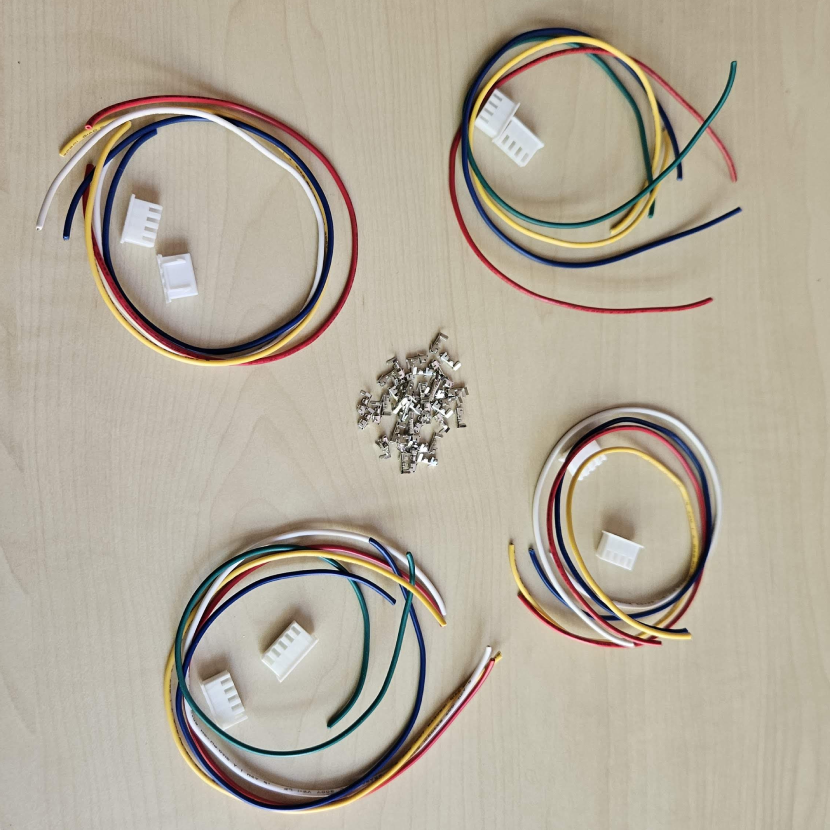
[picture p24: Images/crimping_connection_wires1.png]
Crimping connection wires


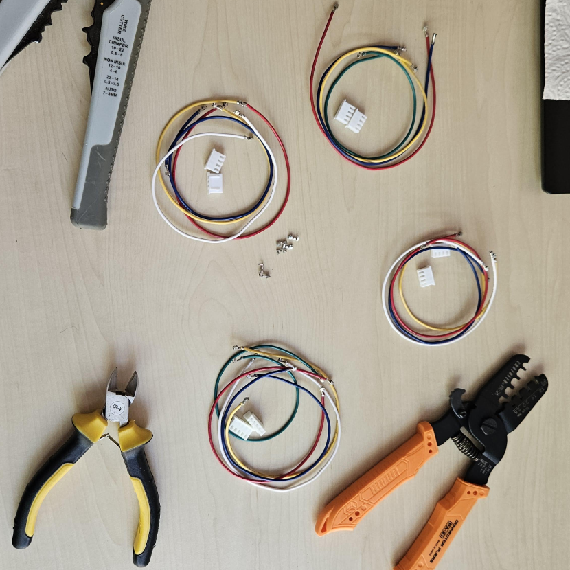
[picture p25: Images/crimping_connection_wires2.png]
Crimping connection wires 2


NOTE Check the order of the wires for both ends of the wires. They should match with the order on the PCBs (use the labels on the silkscreen on the PCBs). Below you can see one of them:

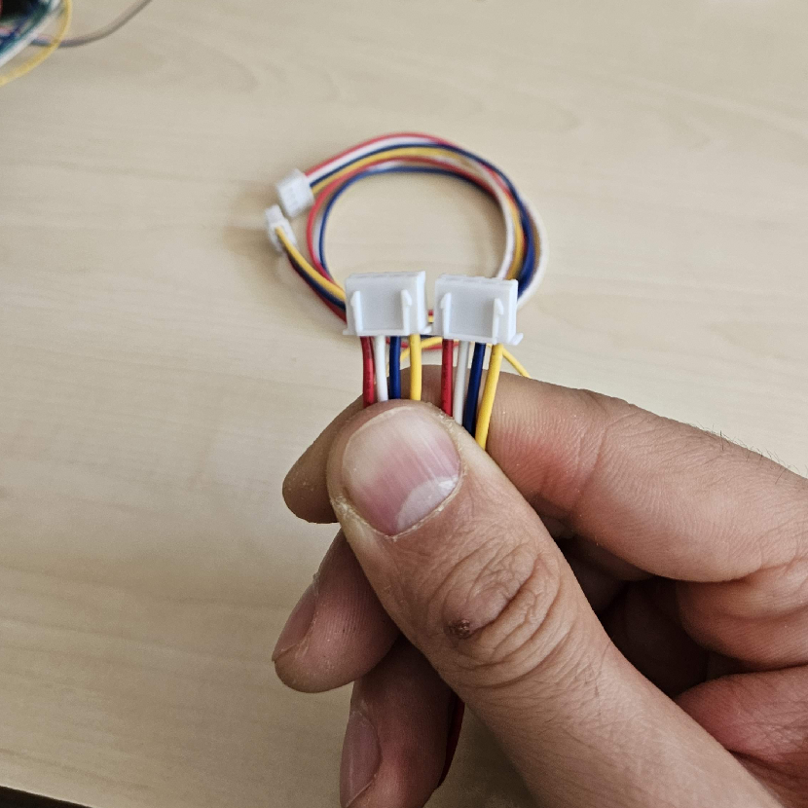
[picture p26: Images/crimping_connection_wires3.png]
Crimping connection wires 3


## Solder pins to the third-party components

1. Solder 2x 5-pin 2.54mm pitch male headers to each of the two [SparkFun HX711 Load Cell Amplifier](https://eu.robotshop.com/products/hx711-load-cell-amplifier?variant=42600661942440) modules.

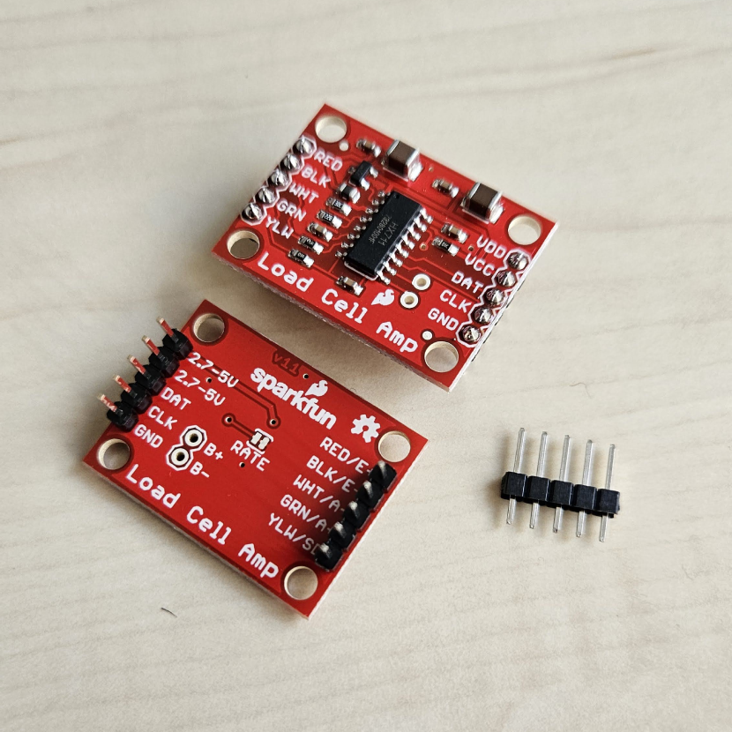
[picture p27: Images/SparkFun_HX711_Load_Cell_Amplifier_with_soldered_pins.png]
SparkFun HX711 Load Cell Amplifier with soldered pins


2. Solder a 7-pin 2.54mm pitch male header and a 2-pin screw terminal with 3.5mm pitch to the [SparkFun MAX98357A I2S Audio Breakout](https://opencircuit.shop/product/sparkfun-i2s-audio-breakout-max98357a).

3. Solder a 4-pin 2.54mm pitch male header to the [AZDelivery ST7735 SPI TFT Display 1.8 inch 128 x 160 pixels](https://www.amazon.nl/dp/B078J5TS2G/) for the SD card interface. Mine came with the pins of the TFT display interface already soldered.

## Solder the pin headers and the other components to the custom PCBs

1. Solder the pin headers and the other components to the custom PCBs

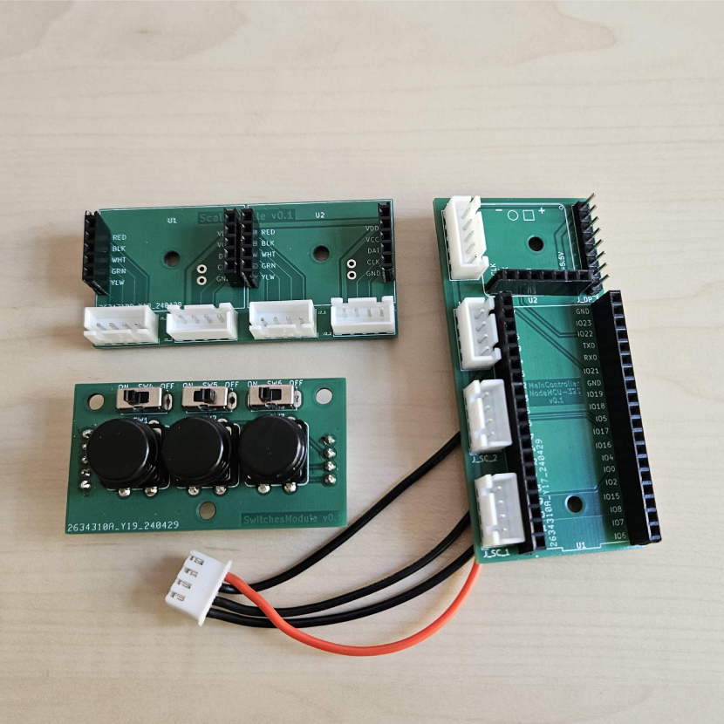
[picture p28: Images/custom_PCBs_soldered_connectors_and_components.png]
Custom PCBs with soldered connectors and components


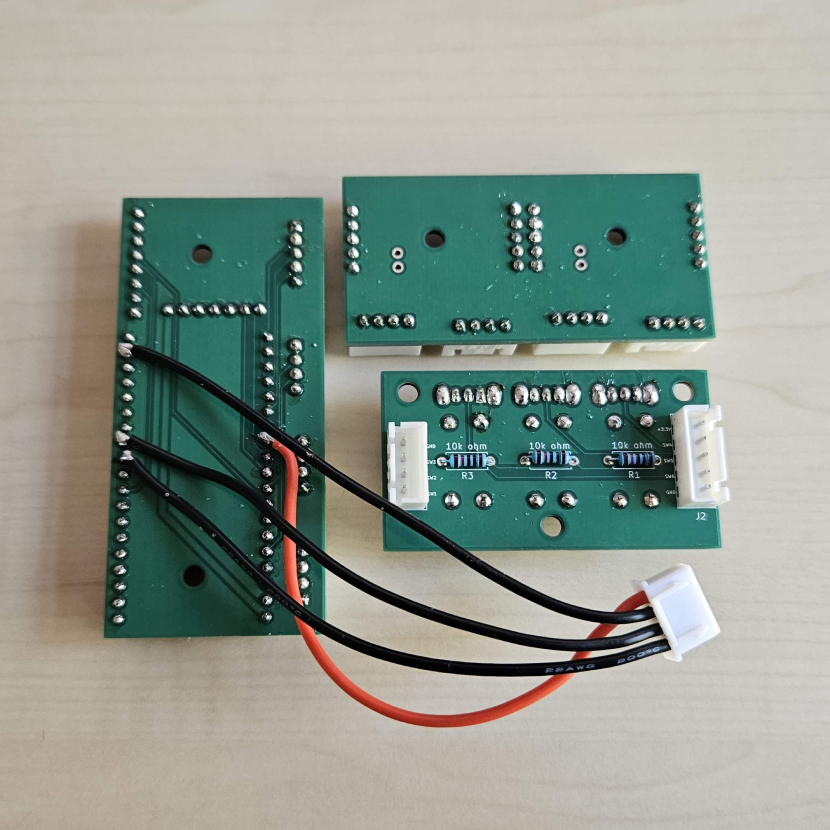
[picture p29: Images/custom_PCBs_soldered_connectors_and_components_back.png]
Custom PCBs with soldered connectors and components back


2. TEMP (hopefully) solder the 4-pin JST-XH to the MainControllerNodeMCU-32S

NOTE At the moment the custom PCB for the MainControllerNodeMCU-32S module needs a small improvement. Currently it's missing a 4-pin connection for interfacing with the SD card on the TFT display. You can either modify the project and add the connector on the PCB (before placing the order), or make the 4 connections manually (solder the 4 wires directly on the PCB, picture found below). Follow the issue on GitHub for updates: [\[PCB\] Update Custom PCB for MainControllerNodeMCU-32S #8](https://github.com/ovidiurosu90/psh-portable-smart-hangboard/issues/8)

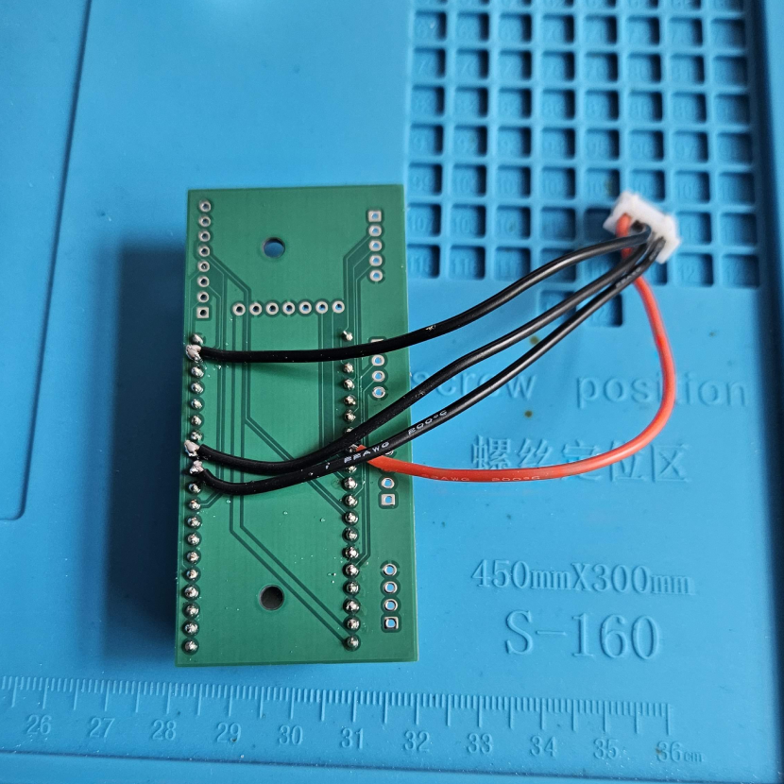
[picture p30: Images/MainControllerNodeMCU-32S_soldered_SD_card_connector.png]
MainControllerNodeMCU-32S with soldered SD card connector


## 3D-print the plastic components

1. Setup your project in Fusion 360 by following the instructions from [CAD/README.md](CAD/README.md)

2. Export the following bodies one by one by right clicking on them > 'Save as Mesh' > OK > Check 'Save to my computer' > 'Save':
- from component 'PSH Scale Assembly May 2024 v4':
  - HangingHoldFlat\_200x50
  - HangingHoldChassis
  - HangingHoldCap
  - MountingHold
  - MountingHoldCap
- from component 'PSH SmartBox Assembly May 2024 v5 / SmartBox':
  - SmartBoxBase
- from component 'ScaleSmartBoxMount':
  - ScaleSmartBoxMount

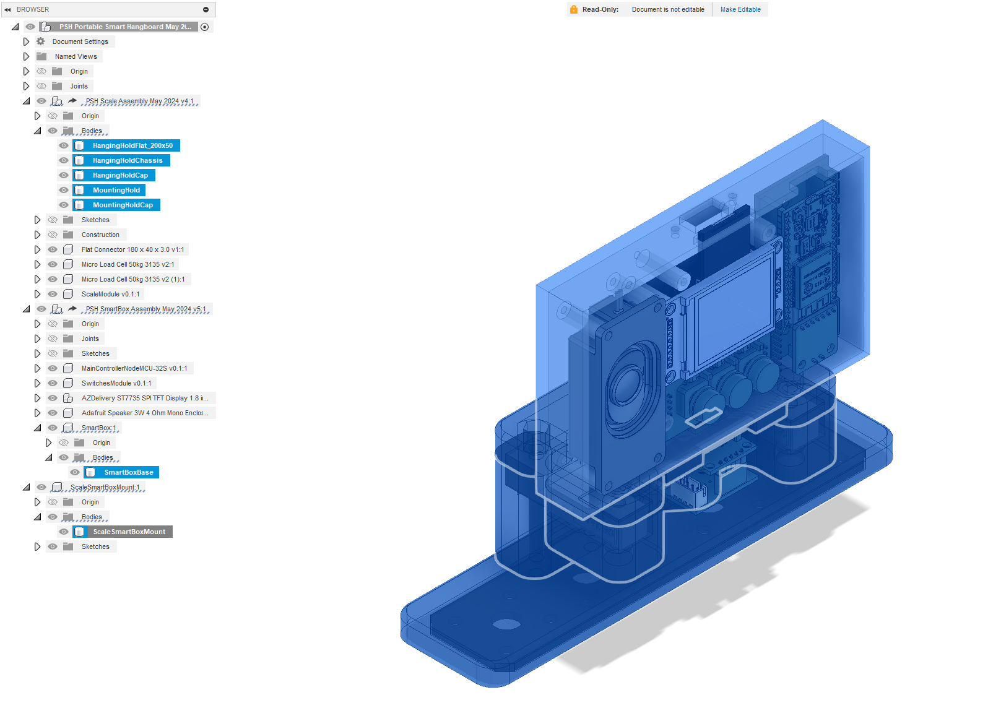
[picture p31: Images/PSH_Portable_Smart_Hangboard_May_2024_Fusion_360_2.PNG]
PSH Portable Smart Hangboard - May 2024 - Fusion 360 (2)


3. Slice the meshes and prepare the .gcode files that will be used by your 3D printer

NOTE I used [PrusaSlicer 2.7](https://www.prusa3d.com/en/page/prusaslicer_424/), though you can use other tools (e.g. [Ultimaker Cura](https://ultimaker.com/software/ultimaker-cura/)).

For each of the exported meshes (from above), follow the steps:
- open PrusaSlicer
- add the mesh by clicking 'Add...' in the top toolbar, then selecting the relevant file (e.g. ScaleSmartBoxMount\_v2\_20240512.3mf)
- select '0.30mm DRAFT' in the right toolbar > 'Print settings'
- select 'Generic PETG' in the right toolbar > 'Filament'
- (optional) add supports for the components that need them
- select '40%' in the right toolbar > 'Infill'
- for advanced settings, go to 'Print Settings' in the top toolbar
  - 0.3mm layer height
  - 0.2mm first layer height
  - vertical shells: 4 perimeters
  - horizontal shells: solid layers 8 top & 8 bottom
- click 'Slice now'
- click 'Export G-code'
- click 'Save'

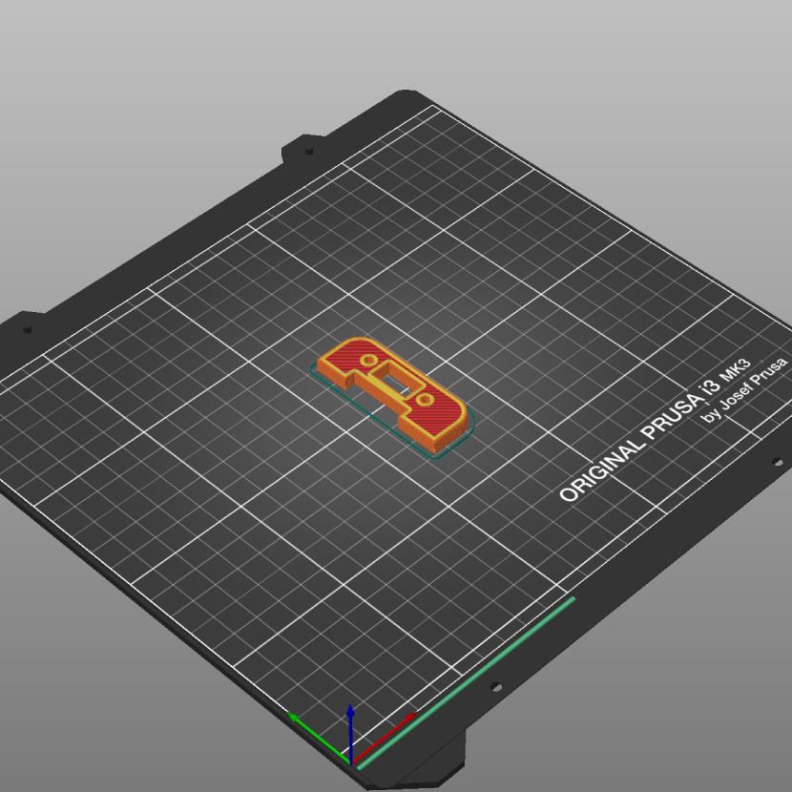
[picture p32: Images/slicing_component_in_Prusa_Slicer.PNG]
Slicing component in Prusa Slicer


4. 3D-print the components by using the .gcode files generated above

NOTE This step depends on your 3d printer and your setup. I prefer to use [OctoPrint](https://octoprint.org/) for managing the printing jobs, though you can directly send the .gcode files to your 3d printer via USB or SD Card.

## Assemble everything

1. Add the M5 nuts and the flat metal plate to the newly printed components

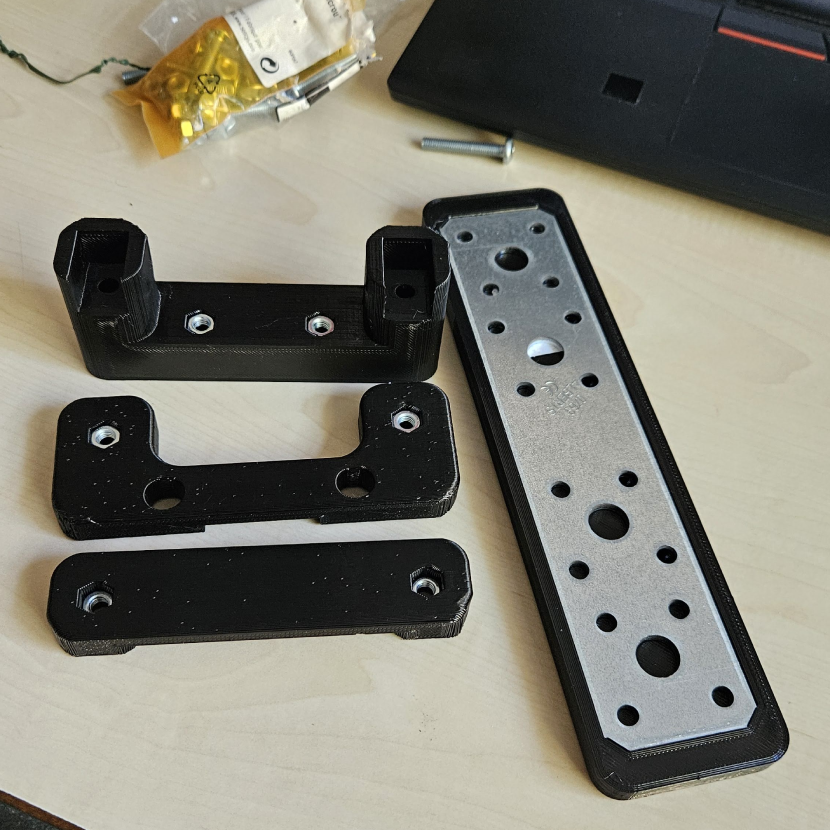
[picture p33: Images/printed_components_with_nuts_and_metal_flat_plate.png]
Printed components with nuts and metal flat plate


2. Assemble the SmartBox

3. Assemble the Scale

4. Connect the two with the ScaleSmartBoxMount. When done, the full assembly should look like this:

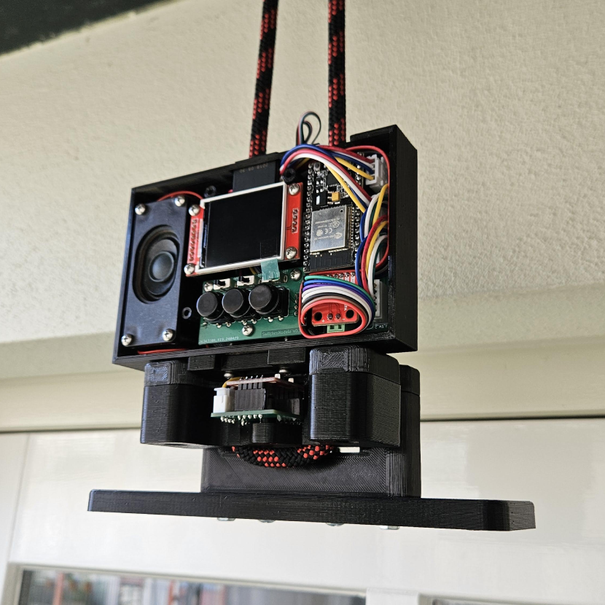
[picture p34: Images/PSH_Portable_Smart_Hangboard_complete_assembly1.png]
PSH Portable Smart Hangboard - Complete Assembly (1)


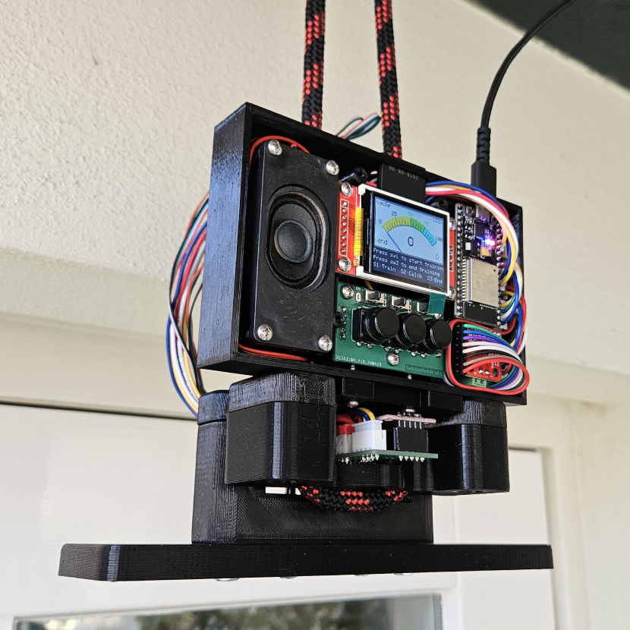
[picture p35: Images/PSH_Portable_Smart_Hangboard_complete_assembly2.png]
PSH Portable Smart Hangboard - Complete Assembly (2)


## Setup the remote API
Follow the instructions from [Web/README.md](Web/README.md) to set up the remote API.

NOTE You will need access to some kind of third party hosting where you can set up and configure a web server.

## Program the main controller
Follow the instructions from [Arduino/README.md](Arduino/README.md) to program the main controller (MainControllerNodeMCU-32S).

## START TRAINING! No More Excuses!

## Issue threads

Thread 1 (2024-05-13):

Configure toggle switches

ovidiurosu90, 2024-05-13:
- SW4 (buttons page 2)

> ON - current behavior
> OFF - decrease volume, save to NVM, increase volume

- SW5 (lock for saving to NVM)
> ON - don’t save
> OFF - save

ovidiurosu90, 2024-05-14:
Implemented

Closed 2024-05-14.

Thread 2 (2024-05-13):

Update scale thresholds on the display from the configuration

ovidiurosu90, 2024-05-13:
At the moment, the thresholds on the display are fixed at 50 & 75.
There are parameters in the configuration though they are not taken into account in this case.

Closed 2024-05-14.

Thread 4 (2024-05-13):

Profile boot time - it takes 10s for the switches to be responsive

ovidiurosu90, 2024-05-13:
Investigate where the time is spent before everything is loaded.

ovidiurosu90, 2024-05-16:
It takes 10s to become fully operational:
- 1s to connect to WiFi
- 1s to initialize the TFT display & the Audio module
- 6s to initialize the scale module
- 2s to initialize the trainer module

### LOG

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

ovidiurosu90, 2024-05-16:
10s to boot is acceptable for now; won't spend more time into bringing it down

Closed 2024-05-16.

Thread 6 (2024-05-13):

Add notes in the relevant places that the custom PCB for the MainControllerNodeMCU-32S is missing the connector for the SD card

ovidiurosu90, 2024-05-13:
At the moment, the 4 wires are soldered directly on the PCB. This is dirty and error prone, we should add another connector for completeness.

ovidiurosu90, 2024-05-14:
Implemented

Closed 2024-05-14.

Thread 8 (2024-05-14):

Update Custom PCB for MainControllerNodeMCU-32S

ovidiurosu90, 2024-05-14:
MainControllerNodeMCU-32S v0.1-20240428

- [ ] Connect the SD Card reader on the TFT SPI display to the ESP32-S microcontroller via an JST-XH 4-pin connector
- [ ] Add labels to J_DP_1
- [ ] Change the footprint of J_DP_1 to a JST-XH 8-pin connector

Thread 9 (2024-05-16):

Fetch training configuration before each training

ovidiurosu90, 2024-05-16:
At the moment, the configuration for the training is fetched at boot time. If you want to do 2 different trainings, you have to reset the device.

ovidiurosu90, 2024-05-16:
Implemented

Closed 2024-05-16.

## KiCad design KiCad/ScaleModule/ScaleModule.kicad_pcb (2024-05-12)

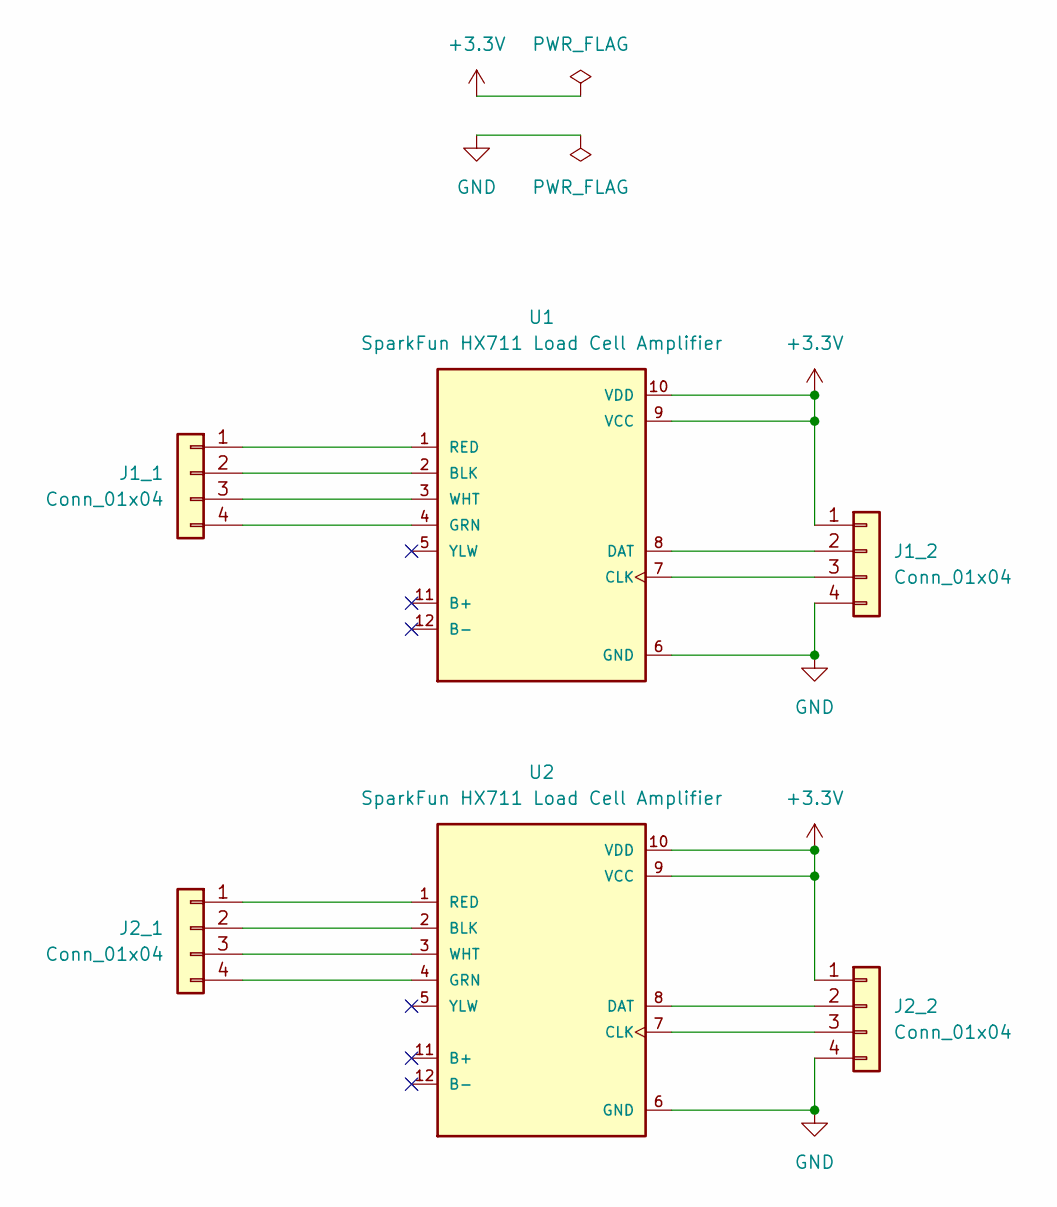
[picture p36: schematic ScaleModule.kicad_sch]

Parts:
J1_1, J1_2, J2_1, J2_2: Conn_01x04; JST_XH_B4B-XH-A_1x04_P2.50mm_Vertical
U1, U2: SparkFun HX711 Load Cell Amplifier

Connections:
+3.3V: J1_2.1, J2_2.1, U1.9 (VCC), U1.10 (VDD), U2.9 (VCC), U2.10 (VDD)
GND: J1_2.4, J2_2.4, U1.6 (GND), U2.6 (GND)
unnamed: J1_1.1, U1.1 (RED)
unnamed: J1_1.2, U1.2 (BLK)
unnamed: J1_1.3, U1.3 (WHT)
unnamed: J1_1.4, U1.4 (GRN)
unnamed: J1_2.2, U1.8 (DAT)
unnamed: J1_2.3, U1.7 (CLK)
unnamed: J2_1.1, U2.1 (RED)
unnamed: J2_1.2, U2.2 (BLK)
unnamed: J2_1.3, U2.3 (WHT)
unnamed: J2_1.4, U2.4 (GRN)
unnamed: J2_2.2, U2.8 (DAT)
unnamed: J2_2.3, U2.7 (CLK)

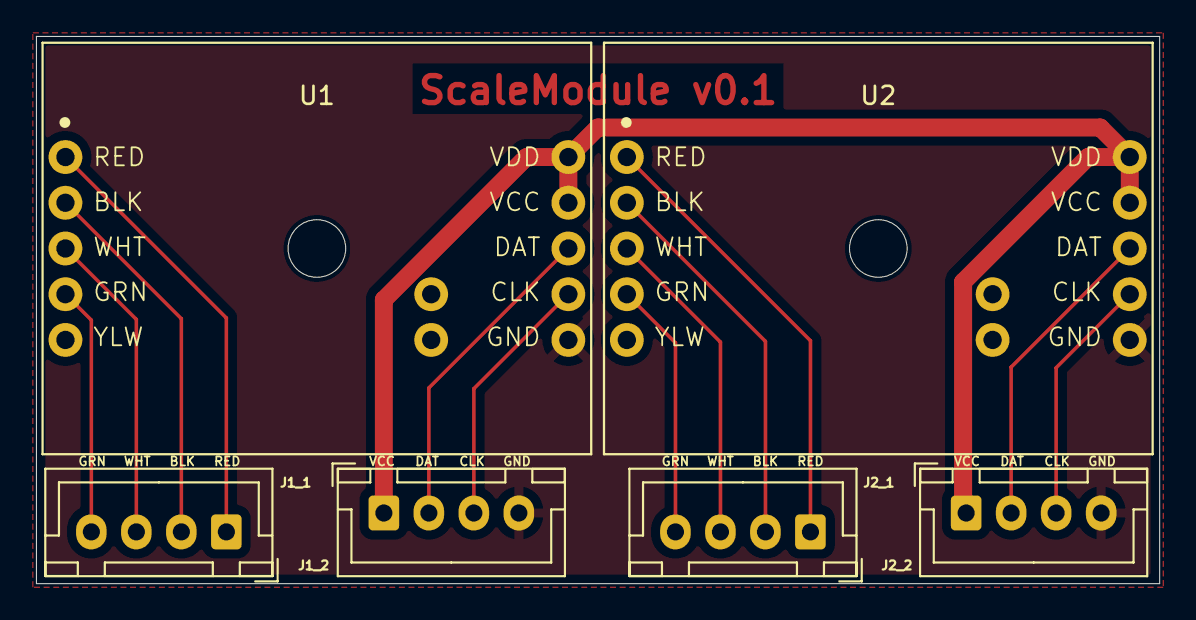
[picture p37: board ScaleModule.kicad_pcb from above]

Board: 2 copper layers, 62.4 x 30.4 mm, 8 parts (0 on the bottom side), 14 nets.

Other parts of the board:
MountingHole1, MountingHole2: MountingHole_3.2mm_M3

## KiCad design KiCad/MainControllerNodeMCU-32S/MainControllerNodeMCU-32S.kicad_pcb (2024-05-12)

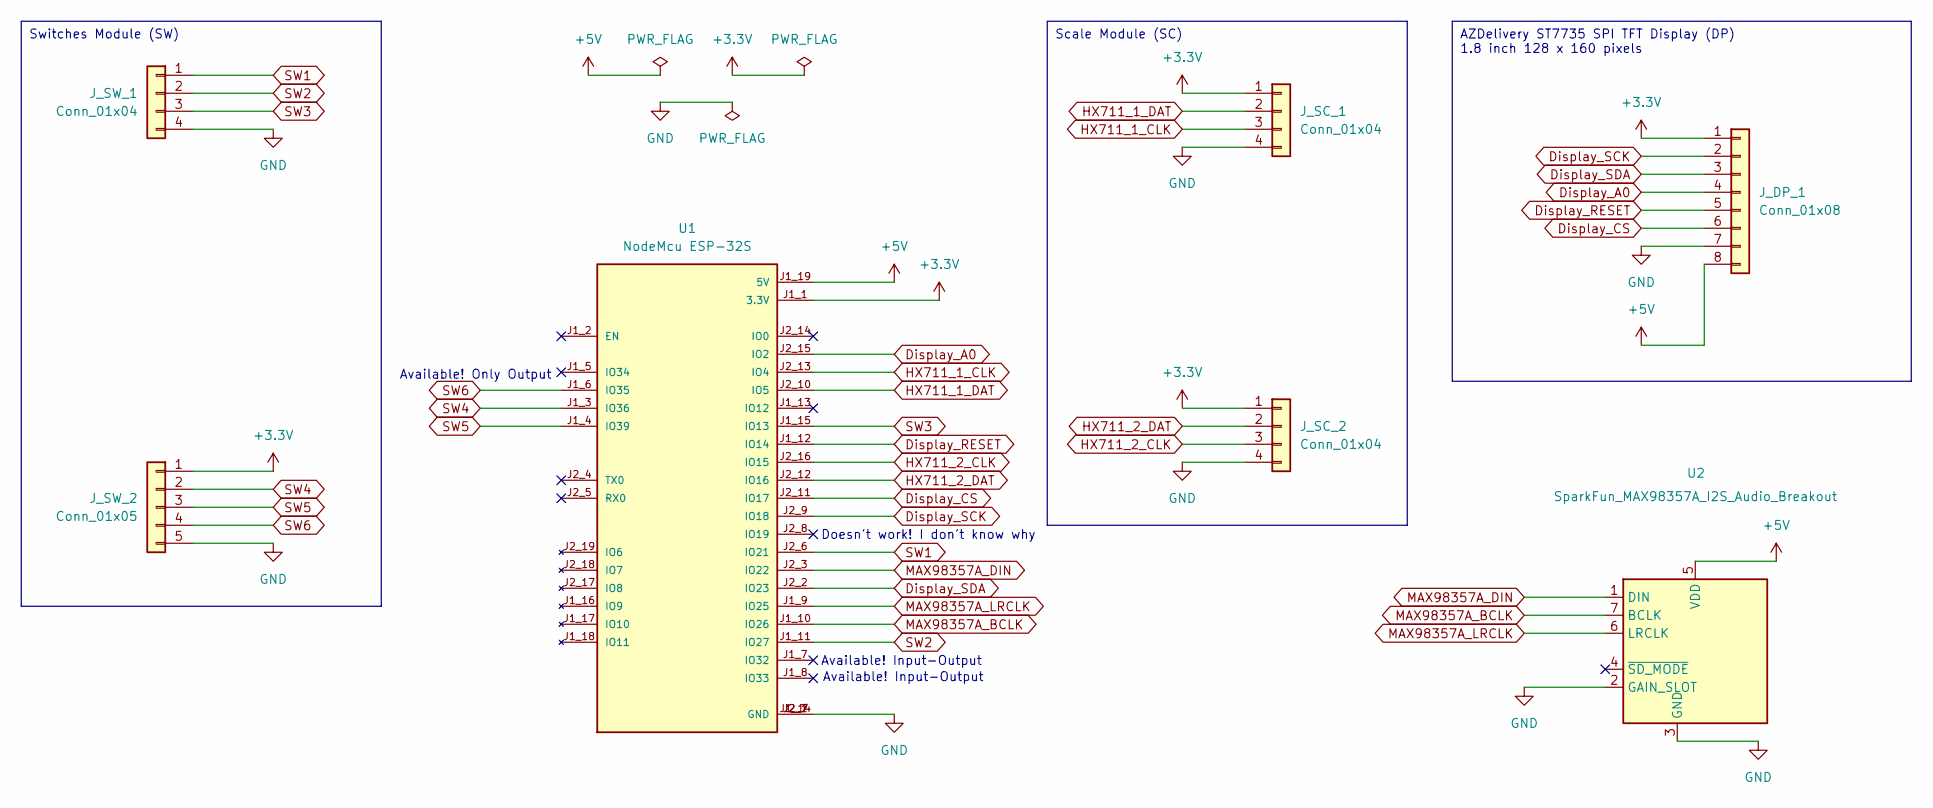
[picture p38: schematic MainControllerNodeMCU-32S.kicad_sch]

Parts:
J_DP_1: Conn_01x08; PinHeader_1x08_P2.54mm_Vertical
J_SC_1, J_SC_2: Conn_01x04; JST_XH_B4B-XH-A_1x04_P2.50mm_Vertical
J_SW_1: Conn_01x04; JST_XH_B4B-XH-A_1x04_P2.50mm_Vertical
J_SW_2: Conn_01x05; JST_XH_B5B-XH-A_1x05_P2.50mm_Vertical
U1: NodeMcu ESP-32S; PARTREV V1
U2: SparkFun_MAX98357A_I2S_Audio_Breakout; SparkFun MAX98357A I2S Audio Breakout

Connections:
+3.3V: J_DP_1.1, J_SC_1.1, J_SC_2.1, J_SW_2.1, U1.J1_1 (3.3V)
+5V: J_DP_1.8, U1.J1_19 (5V), U2.5 (VDD)
Display_A0: J_DP_1.4, U1.J2_15 (IO2)
Display_CS: J_DP_1.6, U1.J2_11 (IO17)
Display_RESET: J_DP_1.5, U1.J1_12 (IO14)
Display_SCK: J_DP_1.2, U1.J2_9 (IO18)
Display_SDA: J_DP_1.3, U1.J2_2 (IO23)
GND: J_DP_1.7, J_SC_1.4, J_SC_2.4, J_SW_1.4, J_SW_2.5, U1.J1_14 (GND), U1.J2_1 (GND), U1.J2_7 (GND), U2.2 (GAIN_SLOT), U2.3 (GND)
HX711_1_CLK: J_SC_1.3, U1.J2_13 (IO4)
HX711_1_DAT: J_SC_1.2, U1.J2_10 (IO5)
HX711_2_CLK: J_SC_2.3, U1.J2_16 (IO15)
HX711_2_DAT: J_SC_2.2, U1.J2_12 (IO16)
MAX98357A_BCLK: U1.J1_10 (IO26), U2.7 (BCLK)
MAX98357A_DIN: U1.J2_3 (IO22), U2.1 (DIN)
MAX98357A_LRCLK: U1.J1_9 (IO25), U2.6 (LRCLK)
SW1: J_SW_1.1, U1.J2_6 (IO21)
SW2: J_SW_1.2, U1.J1_11 (IO27)
SW3: J_SW_1.3, U1.J1_15 (IO13)
SW4: J_SW_2.2, U1.J1_3 (IO36)
SW5: J_SW_2.3, U1.J1_4 (IO39)
SW6: J_SW_2.4, U1.J1_6 (IO35)

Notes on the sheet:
Switches Module (SW)
Scale Module (SC)
AZDelivery ST7735 SPI TFT Display (DP) 1.8 inch 128 x 160 pixels
Available! Only Output
Available! Input-Output
Doesn't work! I don't know why

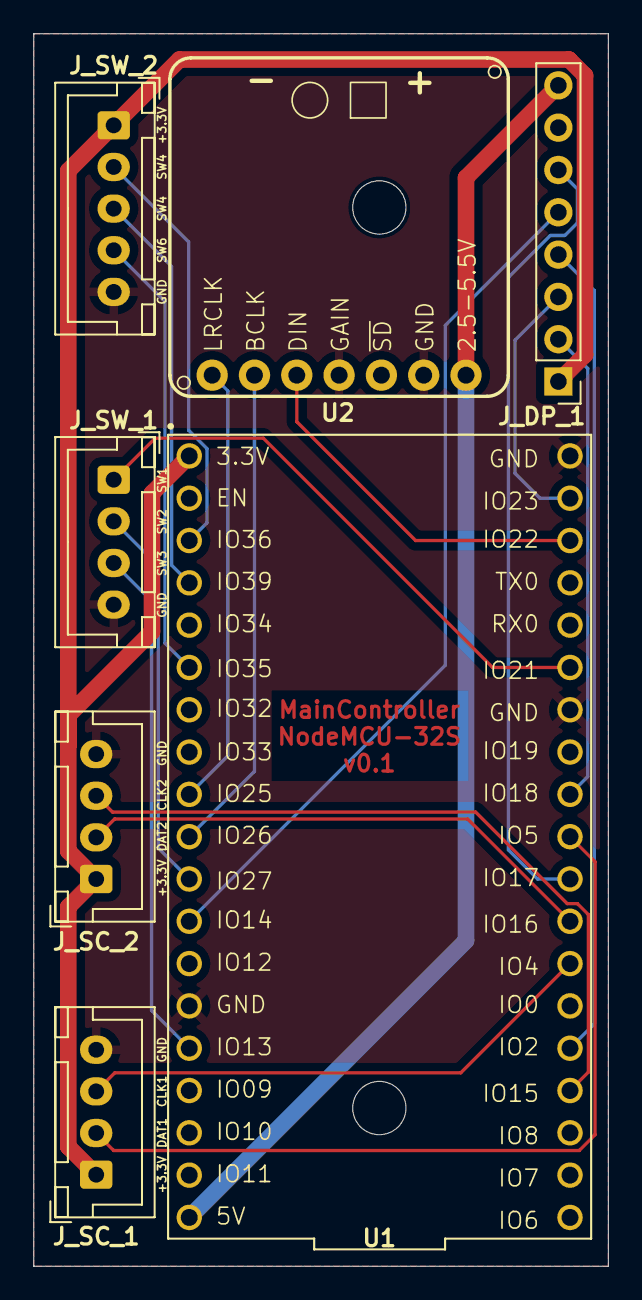
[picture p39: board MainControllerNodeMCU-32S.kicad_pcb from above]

Board: 2 copper layers, 34.5 x 74.0 mm, 9 parts (0 on the bottom side), 21 nets.

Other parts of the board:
MountinHole2: MountingHole_3.2mm_M3
MountingHole1: MountingHole_3.2mm_M3

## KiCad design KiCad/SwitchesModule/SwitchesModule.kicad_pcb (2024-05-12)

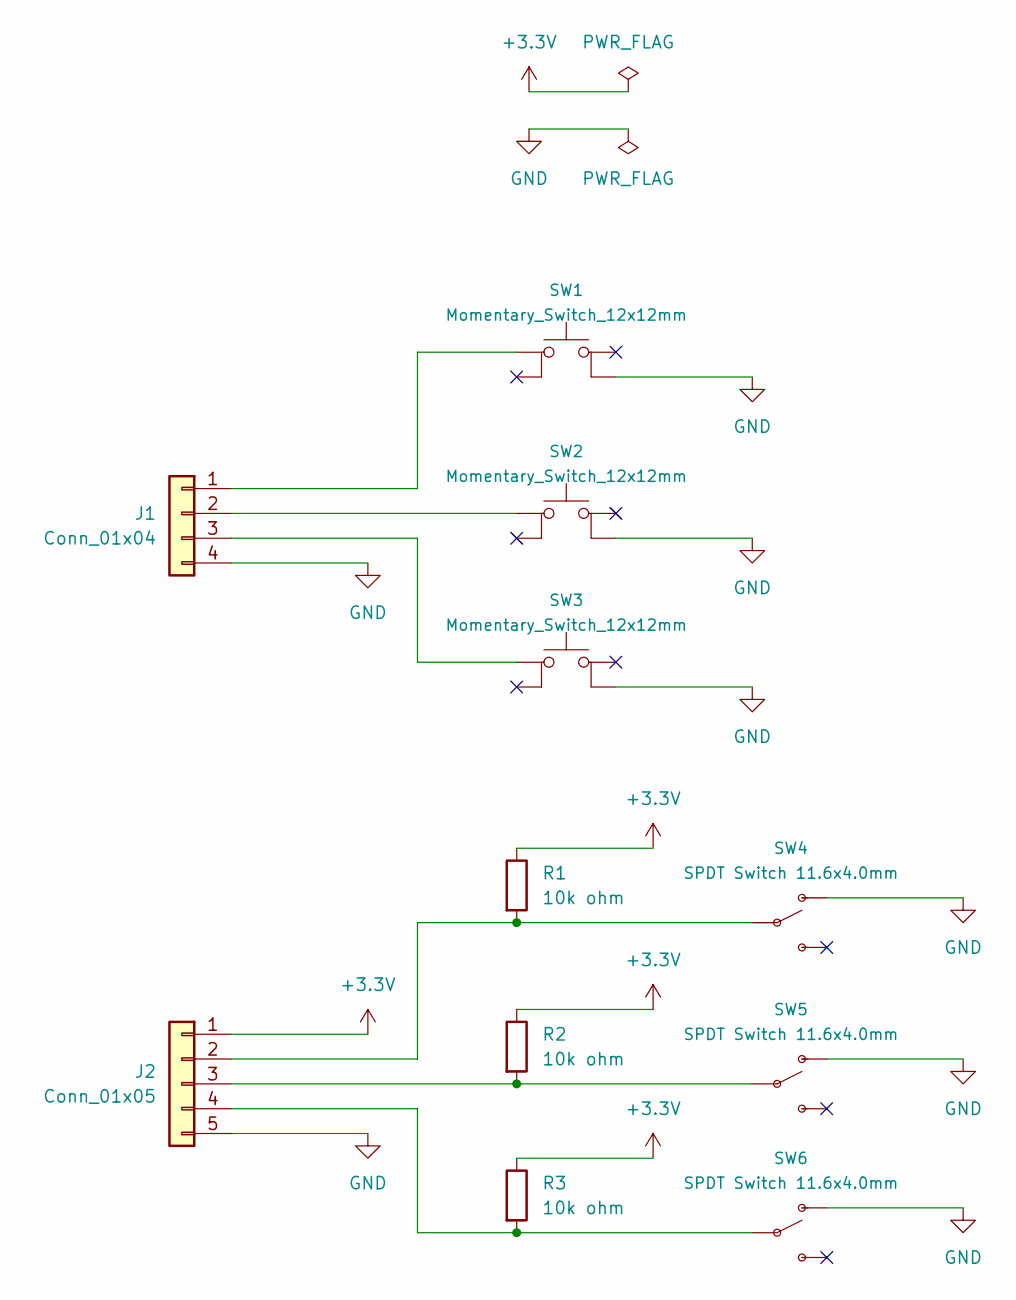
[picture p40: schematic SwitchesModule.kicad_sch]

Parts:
J1: Conn_01x04; JST_XH_B4B-XH-A_1x04_P2.50mm_Vertical
J2: Conn_01x05; JST_XH_B5B-XH-A_1x05_P2.50mm_Vertical
R1, R2, R3: 10k ohm; R_Axial_DIN0207_L6.3mm_D2.5mm_P7.62mm_Horizontal
SW1, SW2, SW3: Momentary_Switch_12x12mm; Momentary Switch 12x12mm
SW4, SW5, SW6: SPDT Switch 11.6x4.0mm

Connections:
+3.3V: J2.1, R1.1, R2.1, R3.1
GND: J1.4, J2.5, SW1.3 (K), SW2.3 (K), SW3.3 (K), SW4.1 (O), SW5.1 (O), SW6.1 (O)
unnamed: J1.1, SW1.1
unnamed: J1.2, SW2.1
unnamed: J1.3, SW3.1
unnamed: J2.2, R1.2, SW4.2
unnamed: J2.3, R2.2, SW5.2
unnamed: J2.4, R3.2, SW6.2

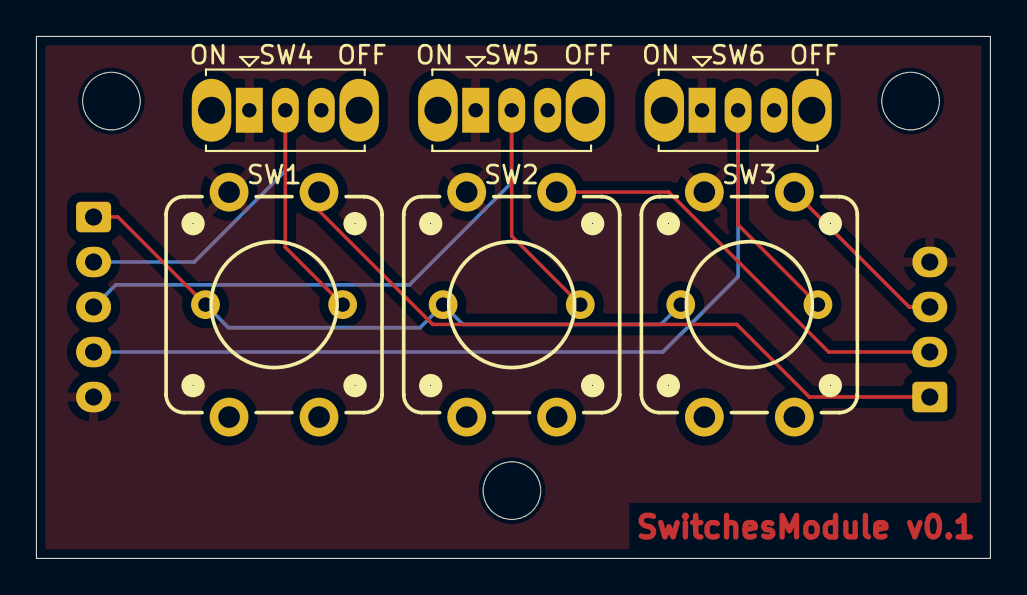
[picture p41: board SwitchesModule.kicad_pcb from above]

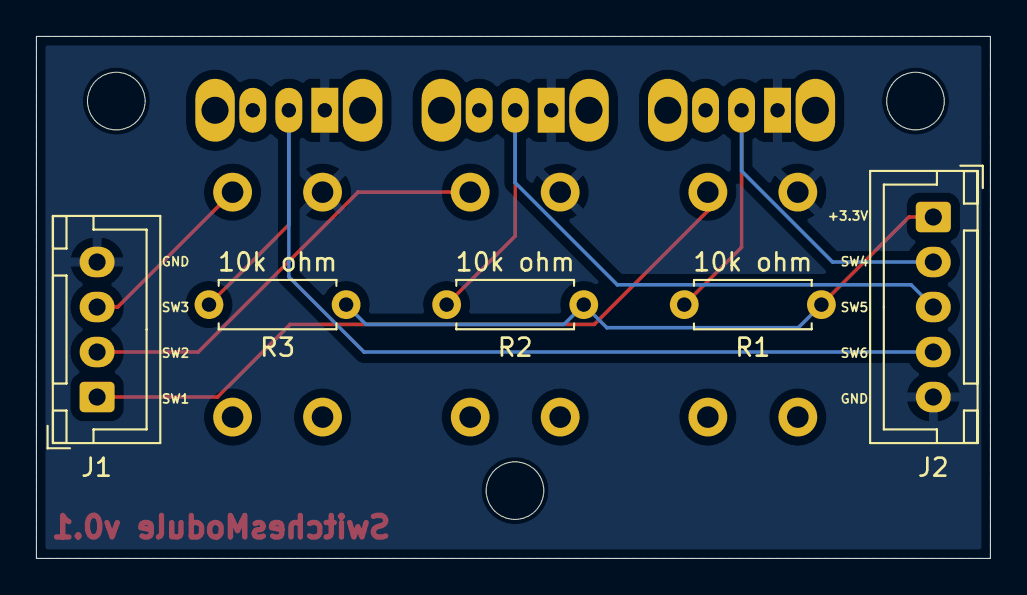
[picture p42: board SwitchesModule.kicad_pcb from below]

Board: 2 copper layers, 53.0 x 29.0 mm, 14 parts (5 on the bottom side), 8 nets.

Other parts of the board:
MountingHole1, MountingHole2, MountingHole3: MountingHole_3.2mm_M3

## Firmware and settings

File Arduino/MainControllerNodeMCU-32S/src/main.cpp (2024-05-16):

#include <MySwitchesModule.h>
#include <MyWiFi.h>
#include <MyTFTeSPI.h>
#include <SD.h>
#include <MyESP32AudioI2S.h>
#include <MyScaleModule.h>
#include <MyTrainer.h>
#include <MyTaskRunner.h>

MySwitchesModule* mySwitchesModule;
MyWiFi* myWiFi;
MyTFTeSPI* myTFTeSPI;
MyESP32AudioI2S* myESP32AudioI2S;
MyScaleModule* myScaleModule;
MyTrainer* myTrainer;
MyTaskRunner* myTaskRunner;
bool IS_RUNNING = true;

void sw1PressedCallback()
{
    if (mySwitchesModule->sw4IsToggledOn()) {
        myTrainer->startTraining();
    } else {
        myESP32AudioI2S->decreaseVolume(myTFTeSPI);
    }
}
void sw2PressedCallback()
{
    if (mySwitchesModule->sw4IsToggledOn()) {
        myScaleModule->calibrateHeadless(mySwitchesModule);
    } else {
        if (mySwitchesModule->sw5IsToggledOn()) {
            myESP32AudioI2S->storeVolumeInNVM(myTFTeSPI);
        } else {
            //NOTE Do nothing
        }
    }
}
void sw3PressedCallback()
{
    if (mySwitchesModule->sw4IsToggledOn()) {
        myTrainer->endTraining();
    } else {
        myESP32AudioI2S->increaseVolume(myTFTeSPI);
    }
}
void sw4ToggledCallback()
{
    myTFTeSPI->plotFooter();
}
void sw5ToggledCallback()
{
    myTFTeSPI->plotFooter();
}


void taskFunction0(void* pvParameters)
{
    Serial.print("TaskFunction0 running on core "); Serial.println(xPortGetCoreID());

    for(;;) {
        if (Serial.available() > 0) {
            char inByte = Serial.read();
            if (inByte == '|') {
                Serial.println("Received '|' before upload! Ending training...");
                myTrainer->endTraining();
                // myTFTeSPI->endSD();
                // IS_RUNNING = false;
            }
        }
        if (myWiFi->postResults()) {
            myTFTeSPI->plotFooterLine1("Results posted!");
        }
        delay(50);
    }
}

void taskFunction1(void* pvParameters)
{
    Serial.print("TaskFunction1 running on core "); Serial.println(xPortGetCoreID());

    for(;;) {
        if (IS_RUNNING) {
            myTrainer->addScaleTotalMeasurement(myScaleModule->getTotalMeasurement());
            myTFTeSPI->loop();
        }
        delay(500);
    }
}

void setup()
{
    Serial.begin(115200);

    Serial.println("########### SETUP start"); // debug
    mySwitchesModule = new MySwitchesModule(21, 27, 13, 36, 39, 35);
    Serial.println("########### MySwitchesModule initialized"); // debug

    myWiFi = new MyWiFi(WIFI_SSID, WIFI_PASSPHRASE);
    myWiFi->connect();
    myWiFi->setApiUrl(API_URL);
    myWiFi->setApiToken(API_TOKEN);
    Serial.println("########### Wifi connected"); // debug

    //NOTE The pins are in lib/TFT_eSPI/User_Setup.h
    myTFTeSPI = new MyTFTeSPI(mySwitchesModule);
    myTFTeSPI->initSD(33);
    Serial.println("########### MyTFTeSPI initialized"); // debug

    myESP32AudioI2S = new MyESP32AudioI2S(26, 25, 22);
    myESP32AudioI2S->setVolumeIfNotInNVM(5);
    Serial.println("########### MyESP32AudioI2S initialized"); // debug

    //NOTE Not all ESP-32S pins can be used as outputs
    myScaleModule = new MyScaleModule(5, 4, "_L", 16, 15, "_R");
    myScaleModule->init(myTFTeSPI, myESP32AudioI2S, myWiFi);
    Serial.println("########### MyScaleModule initialized"); // debug

    myTrainer = new MyTrainer(myTFTeSPI, myESP32AudioI2S, myWiFi);
    Serial.println("########### MyTrainer initialized"); // debug

    mySwitchesModule->setSw1PressedCallback(&sw1PressedCallback);
    mySwitchesModule->setSw2PressedCallback(&sw2PressedCallback);
    mySwitchesModule->setSw3PressedCallback(&sw3PressedCallback);
    mySwitchesModule->setSw4ToggledCallback(&sw4ToggledCallback);
    mySwitchesModule->setSw5ToggledCallback(&sw5ToggledCallback);
    Serial.println("########### Added 5 callbacks to the MySwitchesModule"); // debug

    myTaskRunner = new MyTaskRunner();
    myTaskRunner->addTaskCore0(&taskFunction0);
    myTaskRunner->addTaskCore1(&taskFunction1);
    Serial.println("########### Added 2 tasks to the MyTaskRunner"); // debug
    Serial.println("########### SETUP end"); // debug
}

void loop()
{
    if (!IS_RUNNING) {
        return;
    }

    myTrainer->loop();
    myESP32AudioI2S->loop();
    mySwitchesModule->loop();
}

// Audio events (optional)
void audio_info(const char *info){
    Serial.print("info        "); Serial.println(info);
}
void audio_id3data(const char *info){  //id3 metadata
    Serial.print("id3data     ");Serial.println(info);
}
void audio_eof_mp3(const char *info){  //end of file
    Serial.print("eof_mp3     ");Serial.println(info);
}
void audio_showstation(const char *info){
    Serial.print("station     ");Serial.println(info);
}
void audio_showstreamtitle(const char *info)
{
    myTFTeSPI->printStreamTitle(info);
}
void audio_bitrate(const char *info){
    Serial.print("bitrate     ");Serial.println(info);
}
void audio_commercial(const char *info){  //duration in sec
    Serial.print("commercial  ");Serial.println(info);
}
void audio_icyurl(const char *info){  //homepage
    Serial.print("icyurl      ");Serial.println(info);
}
void audio_lasthost(const char *info){  //stream URL played
    Serial.print("lasthost    ");Serial.println(info);
}
void audio_eof_speech(const char *info){
    Serial.print("eof_speech  ");Serial.println(info);
}

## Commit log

2024-05-12 [all] Initial commit
    [19-Pin Header - Female Tall - 2.54mm v2.step, 4-Pin JST-XH - Male Vertical - 2.54mm v3.step, 5-Pin Header - Female Tall - 2.54mm v2.step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]
2024-05-13 [Arduino] Display cycle stats on the screen
2024-05-13 [Arduino] Compute score and display it on the screen
2024-05-13 [Images|KiCad] Adding Images in the root directory + adding documentation & images for KiCad
2024-05-14 [Web|Arduino #3] Send score to Google Sheets via WiFi
2024-05-14 [Arduino #1] Configure toggle switches
2024-05-14 [all|KiCad #6] Add notes in the relevant places that the custom PCB for the MainControllerNodeMCU-32S is missing the connector for the SD card
2024-05-14 [all #5] Add BOM Bill of Materials to GitHub
2024-05-14 [Arduino #2] Update scale thresholds on the display from the configuration
2024-05-16 [Arduino|Web #9] Fetch training configuration before each training
2024-05-16 [Arduino #4] Profile boot time - it takes 10s for the switches to be responsive
2024-09-20 [CAD] Adding Wood non-slippery holds
